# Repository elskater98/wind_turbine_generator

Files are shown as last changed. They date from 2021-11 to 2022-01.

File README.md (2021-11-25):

# Wind Turbine Generator

This repository takes part of the subject Ubiquitous Computing and Embedded systems project of the University of Lleida, being that one a development of a wind turbine generation farm, as for a real client.  

## Project statement

- Desing and evaluate a multi-purpose device including IoT capabilities.
- The main target is a Wind Turbine Generator Farm (WTGF).
- The engineering department has designed a prototype.
- Our target is to evaluate the prototype and determine its weaknesses.
- The prototype is composed by multiple devices; Supervision station, Data providers and a MQTT Broker.

## Project requirements

- There is just only one Supervision Station for the whole WTGF.
- All sensors are placed far from the Supervision Station.
- Temperature and humidity sensors are placed near to the Rotor Hub.
- The Tower movement sensor is placed in the middle of the tower.
- Sensor measurements must be obtained in Real-Time.
- Sensors are controlled by the Data providers and they will show the current sensor readings.
- Whole WTGF data is transferred to the Supervision Station through a MQTT broker.
- The MQTT broker will show graphically the current number of subscribers.
- The maintenance manager requires access to the last 24h data that should be available graphically on the Supervision Station.

## Prototype Schema


## Data Producer 1
### Material
- ESP-01 -> 3.3 V
- Protoboard 
- LCD Screen
- DHT11 -> 3.5 V
- VCC Protoboard adapter (3.3V, 5V)
- ESP Programmer module
- Wires

## Data Producer 2
### Material
- ESP-01 -> 3.3 V
- Protoboard 
- LCD Display
- Accelerometer (ADXL345) -> 3.3 V
- VCC Protoboard adapter (3.3V, 5V)
- ESP Programmer module
- Wires
- I2C – LCD Adapter

## MQTT Broker
### Material
- NodeMCU
- Breadboard
- MCP23017
- Wires
- Segment LED Bar
- I2C Bus

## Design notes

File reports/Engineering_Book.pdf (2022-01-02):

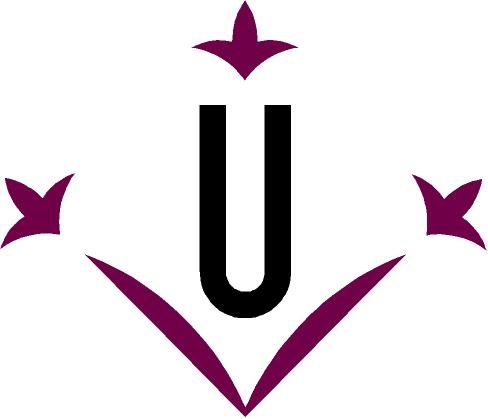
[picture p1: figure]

# University of Lleida

## Master’s Degree in Informatics Engineering

## Higher Polythecnic School

# Engineering Book

## Ubiquitous Computing and Embedded Systems

Francesc Contreras

Albert P´erez

Marc Visa

January 3, 2022

## Table of contents

1 Introduction | 1
2 Document structure | 1
3 Project statement | 2
3.1 Project requirements | | 3
3.2 User stories | | 3
4 Methodology | 4
5 Product Backlog Items | 5
6 Sprint Diary | 7
6.1 Sprint 1 | | 7
6.2 Sprint 2 | | 12
6.3 Sprint 3 | | 16
7 Project Flow | 20
8 Final Project Conclusions | 22

## List of Figures

1 | Electronic engineering department - WTGF Hardware Proposal | | 2
2 | Scrum methodology | | 4
3 | Sprint 1 - Cummulative-flow graph | | 10
4 | Sprint 1 - Burn-down graph | | 11
5 | Sprint 2 - Cummulative-flow graph | | 14
6 | Sprint 2 - Burn-down graph | | 15
7 | Sprint 3 - Cummulative-flow graph | | 18
8 | Sprint 3 - Burn-down graph | | 19
9 | Whole project flow | | 20
10 | Final project task table report | | 20
11 | Final project board view | | 21

## 1 Introduction

This document introduce the “Wind Turbine Generator Farm” (WTGF) project statement detailing the project requirements and the user stories related, since the aim is to concert the development process.

Hence, the purpose of this document is focused on describing the development of the project presenting the task distribution and the sprints made, but also, the suggestions related to the project that could improve it, and the situations/problems encountered with the proposed solutions.

In closing, there are the final project conclusions from the development team in charge of the project to remark their point of view.

## 2 Document structure

This section looks forward to narrating what is in each section of the document to help understand and facilitate the approach to the contents.

- Project statement: Introduction to the project, to set up the starting point for the whole project development.
- Methodology: Advance the methodology used during the development with some remarks because of the project.
- Product Backlog Items (PBI): The list including all the items present in the PBI, the final assigned score and their relation with the user stories.
- Sprint Diary: Detailed explanation for all the individual sprints during the project acting as a guideline of the process and the work done.
- Final project conclusions: Complete end of the line resulting from the development and over the realization of this document as well as from working with such embedded components and some contributions regarding personal opinion.

1

## 3 Project statement

The following is listed the starting point of the project:

- We work on developing embedded components able to manage and supervise machines.
- We have received a petition to design and evaluate a multi-purpose device including Internet of Things (IoT) capabilities.
- The main target is a Wind Turbine Generator Farm (WTGF).
- The engineering department has designed a prototype (Fig. 2).
- Our target is to evaluate the prototype and determine its weaknesses.
- The prototype is composed by multiple devices; the Supervision station (Data Consumer), the Data Producers and a MQTT Broker.

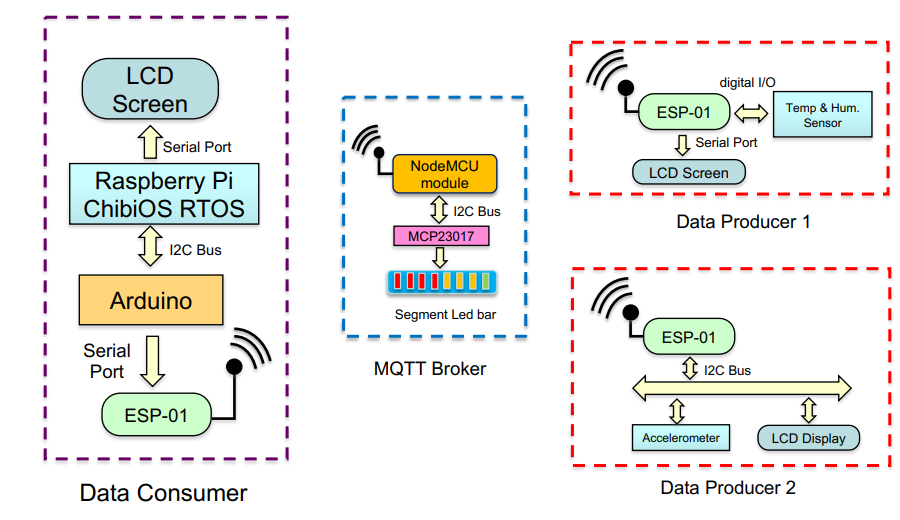
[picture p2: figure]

Figure 1: Electronic engineering department - WTGF Hardware Proposal

2

### 3.1 Project requirements

The following are the requirements presented:

- There is just only one Supervision station for the whole WTGF.
- All sensors are placed far from the Supervision station.
- Temperature and humidity sensors are placed near to the Rotor Hub.
- The Tower movement sensor is placed in the middle of the tower.
- Sensor measurements must be obtained in Real-Time.
- Sensors are controlled by the Data producers and they will show the current sensor readings.
- Whole WTGF data is transferred to the Supervision station through a MQTT Broker.
- The MQTT Broker will show graphically the current number of subscribers.
- The maintenance manager requires access to the last 24h that should be available graphically on the Supervision station.

### 3.2 User stories

The following are the features/goals to achieve:

- It is necessary to obtain the temperature and humidity at the top of the WTFG.
- It is necesssary to determine the WTFG tower movement.
- Sensor data must be must be sent to a Supervision station.
- MQTT Broker must show the current number of connections (percentatge).
- Maintenance manager requires graphically representation of the obtained sensor data, within the last 24h, in the Supervision station.

3

## 4 Methodology

At the project start-up, one of the main anchors that should be defined is the development methodology. In our case, as we were forming a group of engineers to work together, and because of the requirements, the Scrum methodology got the place.

Scrum is an agile development methodology, currently commonly widespread, based on an iterative and incremental processes. The primary objective of Scrum is to satisfy the customer’s need through an environment of transparency in communication, collective responsability and continuous progress.

In this way, we could define sprints and assure a quick an understandable communication to the customers/stakeholders, even doing two-week reports and progress presentations.

Although we must remark, as we were not full-time dedicated to this project, the daily-meetings were replaced by two-three days meetings. Thus, each team member reported the progress after a quite enough time.

Regarding the tasks that compose the product backlog item (PBI), they were defined and assigned by consensus of the whole development team. Moreover, the estimation story point for each item/task was calulated via the Scrum Poker technique through the next webpage https://scrumpoker.online/ where you can adapt anonymous sessions for each of the participants, thus, we assure a better task ponderation without influence obtaining approximate realistic story points.

Furthermore, we were using a Github repository to keep all the work done, but also, the Zenhub integated tool to manage the Scrum methodology.

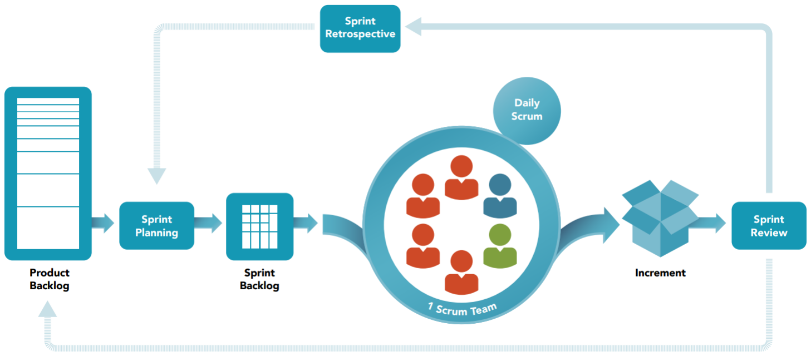
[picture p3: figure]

Figure 2: Scrum methodology

4

## 5 Product Backlog Items

The following is the final PBI of the project. For each task is specified the final assigned score, and the topic related to the user story.

You may see, at the beginning, lots of tasks related to ”Learning” stuff as we needed to introduce ourselves to those components and environments to work with. Since then, there are more concrete ones focused on the development of the project.

Item | Label | Story Point
Revise Material | Good first issue | 2
Read Documentation ESP-01 | Learning | 3
Read Documentation DHT11 | Learning | 3
Prepare Arduino Environment | Learning | 3
First contact with electronic components | Learning | 8
Read Documentation Accelerometer ADXL345 | Learning | 3
Read documentation MCP23017 | Learning | 3
Read documentation LCD Screen/Display | Learning | 2
Read documentation I2C Bus Protocol | Learning | 2
Prepare Raspberry Pi environment | Learning | 3
Read documentation about NodeMCU module | Learning | 3
Data Producer 1 development | Development | 8
Data Producer 2 development | Development | 8
Arduino interaction with ESP-01 | Development | 8
Install ChibiOS to Raspberry Pi | Development | 3
Data log and Screen representation | Development | 8

Table 1: Product Backlog 1/2

5

Item | Label | Story Point
Ultrasonic LED bar representation | Development | 8
Connect Raspberry Pi to LCD Screen via serial port | Development | 8
MQTT Broker development | Development | 13
Arduino interaction with Raspberry Pi | Bug | 8
Sprint 1 documentation | Documentation | 8
Sprint 2 documentation | Documentation | 8
Sprint 3 documentation | Documentation | 8
Data Producer 1 documentation | Documentation | 8
Data Producer 2 documentation | Documentation | 8
MQTT Broker documentation | Documentation | 5
Supervision Station documentation | Documentation | 8
Test Supervision Station | Testing | 13
Test MQTT Broker | Testing | 8
Test Data Producer 1 | Testing | 5
Test Data Producer 2 | Testing | 8

Table 2: Product Backlog 2/2

Finally, there are 31 tasks, getting a total of 194 story points at the end of the project.

6

## 6 Sprint Diary

The purpose of this section is to illustrate the several sprints carried out during the development of the project. In kind, for all individual sprints are detailed:

a) Sprint definition - A short self-explaining sentence related to the user story that identify the sprint goal.
b) Backlog tasks assigned to the sprint.
c) Dedication time to each task (an estimation in hours for the whole team).
d) Percentatge of Sprint completion (or individual tasks).
e) Sprint Review - A short conclusion on the present Sprint, and if required the new PBI organitzation. It could also include any comment related to the team (problems, suggestions, tasks assignments, etc).

### 6.1 Sprint 1

### 6.1.1 Sprint Definition

This first sprint aimed to introduce the team to work with the hardware components and their corresponding software, how to program. Once the team is introduced to the hardware and software of the components, the worked user stories for this sprint were the following:

1. As a user I would like to know to obtain the temperature and humidity at the top of the Wind Turbine Generator.
(a) Acceptable Criteria
i. The Data Producer 1 uses ESP-01 to receive the data from the DHT11 sensor. ii. The ESP-01 sends the data obtained to the LCD Screen to visualize it.
(b) Related Task
i. Data Producer 1 Development.
2. As a user I would like to know the Wind Turbine Generator tower movement.
(a) Acceptable Criteria
i. Data Producer 2 uses ESP-01 to receive the data from the ADXL345 sensor. ii. The ESP-01 sends the data obtained to the LCD Display to visualize it.
(b) Related Task
i. Data Producer 2 Development.

The first user story corresponded to the work-block named Data Producer 1, which components related to were:

- ESP-01
- Temperature and humidity sensor (DHT11)
- LCD Screen

7

The second user story corresponded to the work-block named Data Producer 2, which components related to were:

- ESP-01
- I2C Bus
- Accelerometer (ADXL345)
- LCD Display

Therefore, the sprint goal for this sprint 1 was to have a working version of the Data Producer 1 and the Data Producer 2 of the project, once the team got introduced to work with such components.

### 6.1.2 Sprint Backlog tasks

Task | Label | Story Point
Revise Material | Good first issue | 2
Read documentation ESP-01 | Learning | 3
Read documentation DHT11 | Learning | 3
Prepare Arduino environment | Learning | 3
First contact with electronic components | Learning | 8
Read documentation Accelerometer ADXL345 | Learning | 3
Data Producer 1 development | Enhancement | 8
Data Producer 2 development | Enhancement | 8
Sprint 1 documentation | Documentation | 8
Read documentation LCD Screen/Display | Learning | 3
Read documentation I2C Bus Protocol | Learning | 3
Test Data Producer 1 | Testing | 5
Test Data Producer 2 | Testing | 8

The total story points for the Sprint 1 are 55 points. We should remark this punctuation, as not having previous sprints, are not accurate to the amount of work the team could manage. Just an approximation.

8

### 6.1.3 Dedication time and completion percentage to each task

Task | Completion (%) | Team dedication time (h)
Revise Material | 100 | 1
Read documentation ESP-01 | 100 | 2
Read documentation DHT11 | 100 | 2
Prepare Arduino environment | 100 | 1
First contact with electronic components | 100 | 4
Read documentation Accelerometer ADXL345 | 100 | 2
Data Producer 1 development | 100 | 5
Data Producer 2 development | 20 | 2
Sprint 1 documentation | 100 | 3
Read documentation LCD Screen/Display | 100 | 2
Read documentation I2C Bus Protocol | 100 | 3
Test Data Producer 1 | 100 | 3

The total dedication time for this Sprint 1 is 30h, which means that for 14 days that the sprint lasted, the team dedicated 2:15h per day approximately.

9

### 6.1.4 Sprint Review

The team expected to get the two Data Producers as they are similar but it was realized that it was not as easy as expected when problems arise. The Data Producer 1 was done, just needed a quick clean of the code and integration with the broker, and for the Data Producer 2 needed more work on the I2C Bus.

Finally, the team finished this first sprint with 85% (47/55) of the tasks done, which meant that needed to adjust the number of story points for the next sprint.

The team worked well together and the sprint advanced smoothly. Although everything was new to all of us, from working with Scrum to the chosen technologies, we were well integrated, everyone was very supportive and open to researching, learning, and even teaching if necessary.

Lastly, it is needed to adjust the next sprint amount of story points, so as to finish the remaining tasks/issues for the Data Producer Development, but also taking into account the hours approximatly the team will be able to work on the next sprint.

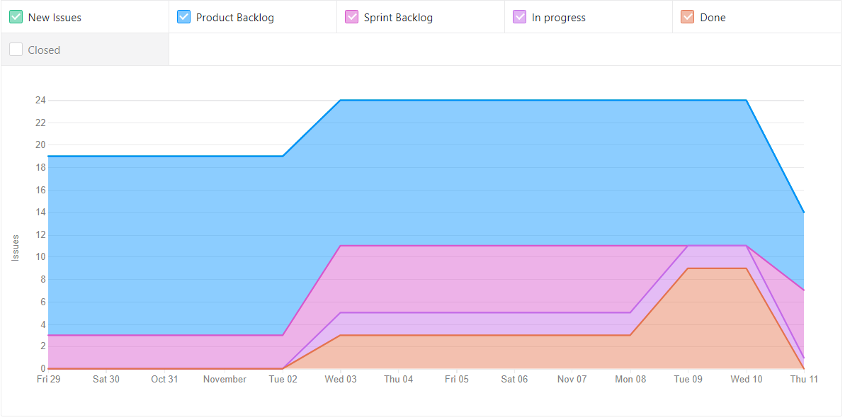
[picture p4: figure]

Figure 3: Sprint 1 - Cummulative-flow graph

10

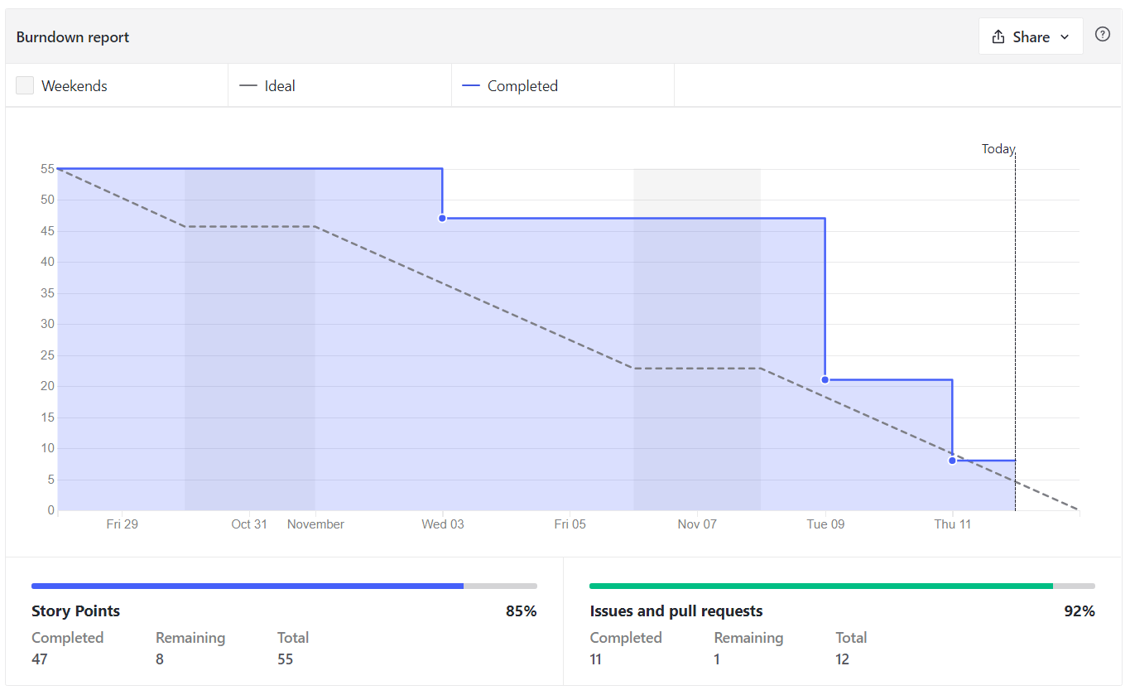
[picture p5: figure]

Figure 4: Sprint 1 - Burn-down graph

11

### 6.2 Sprint 2

### 6.2.1 Sprint Definition

The goal for this sprint was to finish the working version of the Data Producer 2 and having a working version of the MQTT Broker. The user stories that the team worked with during this sprint are the following:

### 6.2.2 User stories

1. As a user I would like to know the Wind Turbine Generator tower movement.
(a) Acceptable Criteria
i. Data Producer 2 uses ESP-01 to receive the data from the ADXL345 sensor. ii. The ESP-01 sends the data obtained to the LCD Display to visualize it.
(b) Related Task
i. Data Producer 2 Development.
2. As a broker I would like to show the current number of connections as a percentage.
(a) Acceptable Criteria
i. The MQTT Broker will receive data from Data Producer 1. ii. The MQTT Broker will receive data from Data Producer 2.
(b) Related Task
i. MQTT Broker Development.
3. As a broker I would like to send received sensor data to a Supervision Station.
(a) Acceptable Criteria
i. The MQTT Broker is able to subscribe to the correspondents topics provided by DP1 and DP2.
ii. The MQTT Broker is able to publish the data received.
(b) Related Task
i. MQTT Broker Development.

The first user story corresponded to the work-block named Data Producer 2, which components related to were:
- ESP-01
- I2C Bus
- Accelerometer (ADXL345)
- LCD Display

The second and third user story corresponded to the work-block named MQTT Broker, which components related to were:
- NodeMCU module
- MCP23017
- Segment LED Bar

12

### 6.2.3 Sprint Backlog tasks

Task | Label | Story Point
Read documentation MCP23017 | Learning | 3
Test MQTT Broker | Testing | 8
Test Data producer 2 | Testing | 8
Data producer 2 development | Enhancement | 13
MQTT Broker development | Enhancement | 13
Read Documentation about NodeMCU module | Learning | 3
Documentation Sprint 2 | Documentation | 8
Data producer 2 documentation | Documentation | 8
MQTT Broker documentation | Documentation | 5

The total story points for the Sprint 2 were 69 points.

### 6.2.4 Dedication time and completion percentage to each task

The total dedication time for the Sprint 2 was 35h, which means that for 14 days that the sprint lasted, the team dedicated 2:30h per day approx.

Task | Completion (%) | Team dedication time (h)
Read documentation MCP23017 | 100 | 2h
Test MQTT Broker | 100 | 1h
Test Data producer 2 | 100 | 2h
Data producer 2 development | 100 | 12h
MQTT Broker development | 100 | 8h
Read Documentation about NodeMCU module | 100 | 2h
Documentation Sprint 2 | 100 | 3h
Data producer 2 documentation | 100 | 2h
MQTT Broker documentation | 100 | 3h

13

### 6.2.5 Sprint Review

The goal for this sprint was to finish the Data Producer 2 module and the MQTT broker module. The team had a lot of difficulties throughout the sprint. Still, it was accomplished a working version of the Data Producer 2, retrieving and printing data from the accelerometer and a working version of the MQTT broker managing publications and subscriptions.

As a result, the team finished this second sprint with a 100% of tasks done, which meant that it is likely to finish the project on time, since in the last sprint it will be worked on the third and last module of the project.

The team worked well together and the sprint advanced smoothly. From now on the team prepared the last issues and tasks to work on the last sprint and hope that the project will be finished by the end of the third sprint if problems will not arise.

Therefore, for the last sprint the team focused on configuring the environment of the Raspberry Pi and installing the ChibiOS, but also on the Arduino, at first, working on the interaction with the corresponding ESP-01, and finally, with the Raspberry PI. Finally, it is also needed to adjust all the components in order to work together following the project schema, and testing all the time if they work properly.

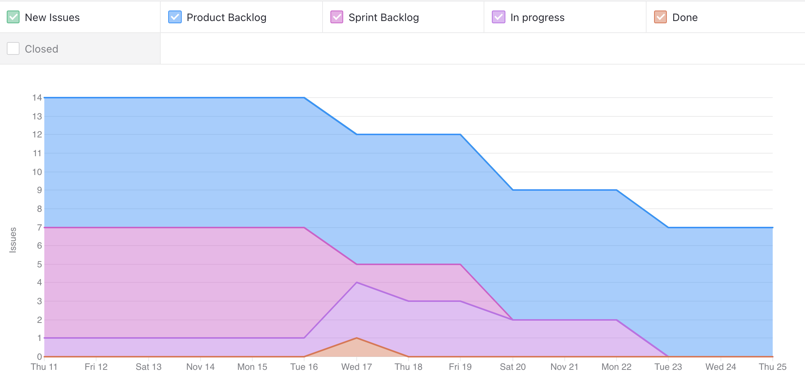
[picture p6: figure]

Figure 5: Sprint 2 - Cummulative-flow graph

14

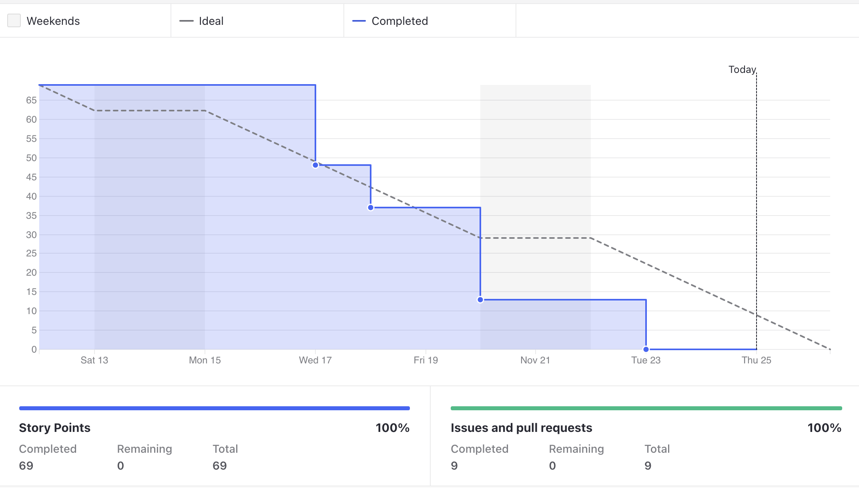
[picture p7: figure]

Figure 6: Sprint 2 - Burn-down graph

15

### 6.3 Sprint 3

### 6.3.1 Sprint Definition

The goal for this sprint was to have a working version of the Supervision Station, which corresponds to the Data Consumer module of the project. The user story that the team worked during this sprint is the following:

### 6.3.2 User stories

1. As a Maintenance manager I would like to represent graphically the obtained sensor data, within the last 24h, in the Supervision Station.
(a) Acceptable Criteria:
i. The Arduino UNO connects to the ESP-01 in order to get the data produced by the Data Producers
ii. The Raspberry Pi connects to the LCD Screen in order to represent the data from the Data Producers
iii. The Arduino UNO and the Raspberry Pi are linked by an I2C Bus where the Raspberry Pi will be the master and the Arduino UNO will be the slave.
iv. The ESP-01 receives the data obtained from the MQTT Broker, which has the data from Data Producer 1 and Data Producer 2.
v. We can see the data provided by the MQTT Broker.
(b) Related Task:
i. Supervision Station Development.

The user story corresponds to the work-block named Data Consumer, which components related to are the following:

- ESP-01
- Arduino UNO
- Raspberry Pi
- LCD Screen

16

### 6.3.3 Sprint Backlog tasks

For this sprint, the total story points is 86 points. This may seem too much compared to the previous sprints, but they wanted to get focused on all task related to the Supervision Station as the last step to conclude the project.

In this way, for the last sprint we expected to finish the remaining tasks if any, and work on the integration of all project parts.

Task | Label | Story Point
Prepare Raspberry Pi environment | Learning | 3
Install ChibiOS to Raspberry Pi | Enhancement | 2
Arduino interaction with R.Pi | Enhancement | 13
Connect Raspberry Pi to LCD Screen via serial port | Enhancement | 8
Arduino interaction with ESP-01 | Enhancement | 8
Test Supervision Station | Testing | 13
Data Consumer: Data log and Screen representation | Enhancement | 13
Sprint 3 documentation | Documentation | 13
Supervision Station documentation | Documentation | 13

### 6.3.4 Dedication time and completion percentage to each task

Task | Completion (%) | Team dedication time (h)
Prepare Raspberry Pi Environment | 100 | 1h
Install ChibiOS to Raspberry Pi | 100 | 1h
Arduino interaction with R.Pi | 80 | 3h
Connect Raspberry Pi to LCD Screen via serial port | 100 | 2h
Arduino interaction with ESP-01 | 50 | 2h
Test Supervision Station | 80 | 5h
Data Consumer: Data log and Screen representation | 70 | 4h
Sprint 3 documentation | 100 | 3h
Supervision Station documentation | 25 | 1h

17

The total dedication time for the Sprint 3 was 22 hours.

The dedication time to this sprint was not as much compared to the others as it can be observed. About 1.5 hours per day. Basically, due to some issues encountered which slowed-down the development, and a short vacation period in mid-sprint.

On the other hand, the main purpose of the sprint was accomplished, as the team got a working version of the Data Consumer, but waiting to test it all.

### 6.3.5 Sprint Review

The main reasons why the team slowed down the development were that they got issues with some failing wires when treating with the SDA connection between the Raspberry Pi and the Arduino when building the component schema for the I2C bus. And also, with the LCD Screen, the one needed for multiple testing because they couldn’t work properly on it since it was failing. Thus, implying not being able to work fairly on the graphics representation, nor even see the values received from the Arduino.

Hence, it can be observed the “Arduino interaction with R.Pi” task and the ”Test Supervision Station” task are not completely finished, specifying a symbolic 80 percent.

In this way, the team should work on finishing and testing the graphics representation on the LCD Screen. Moreover, remained to conclude the Arduino interaction with the ESP to get dynamically the data (this corresponds to the project parts integration), because it could not be dedicated so much time due to the mentioned problems above.

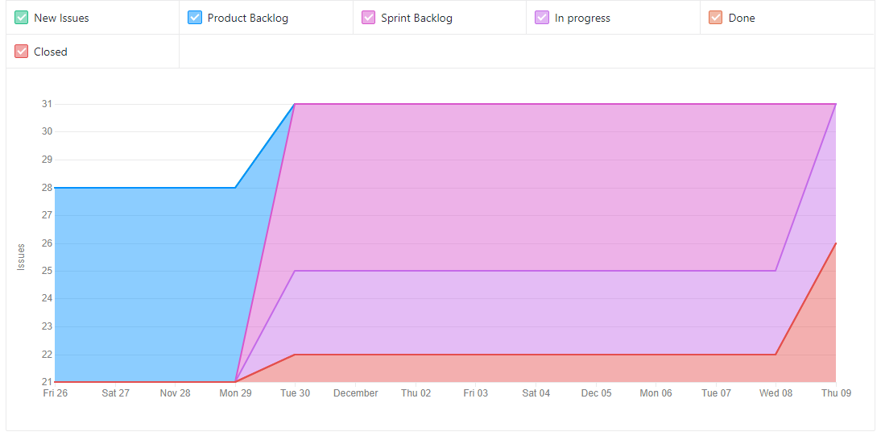
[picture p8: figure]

Figure 7: Sprint 3 - Cummulative-flow graph

18

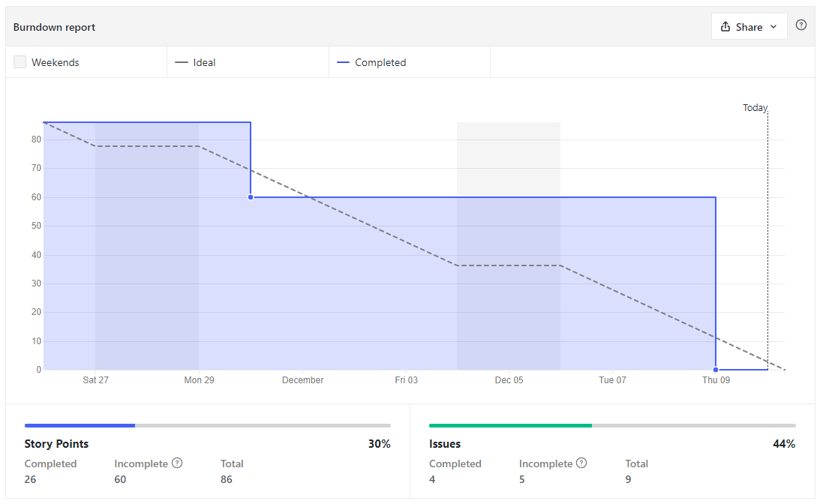
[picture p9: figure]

Figure 8: Sprint 3 - Burn-down graph

From now on the team shall prepare the last issues and tasks to work on the last sprint and they thought that if they keep working as they have done, the project will be finished in time.

Although, the team must got focused on solving the issues encountered on this sprint to finish the remaining tasks and test them all. Mainly the Raspberry Pi and Arduino interaction. And finally, test the whole project parts integration, and carried out the final project documentation.

19

## 7 Project Flow

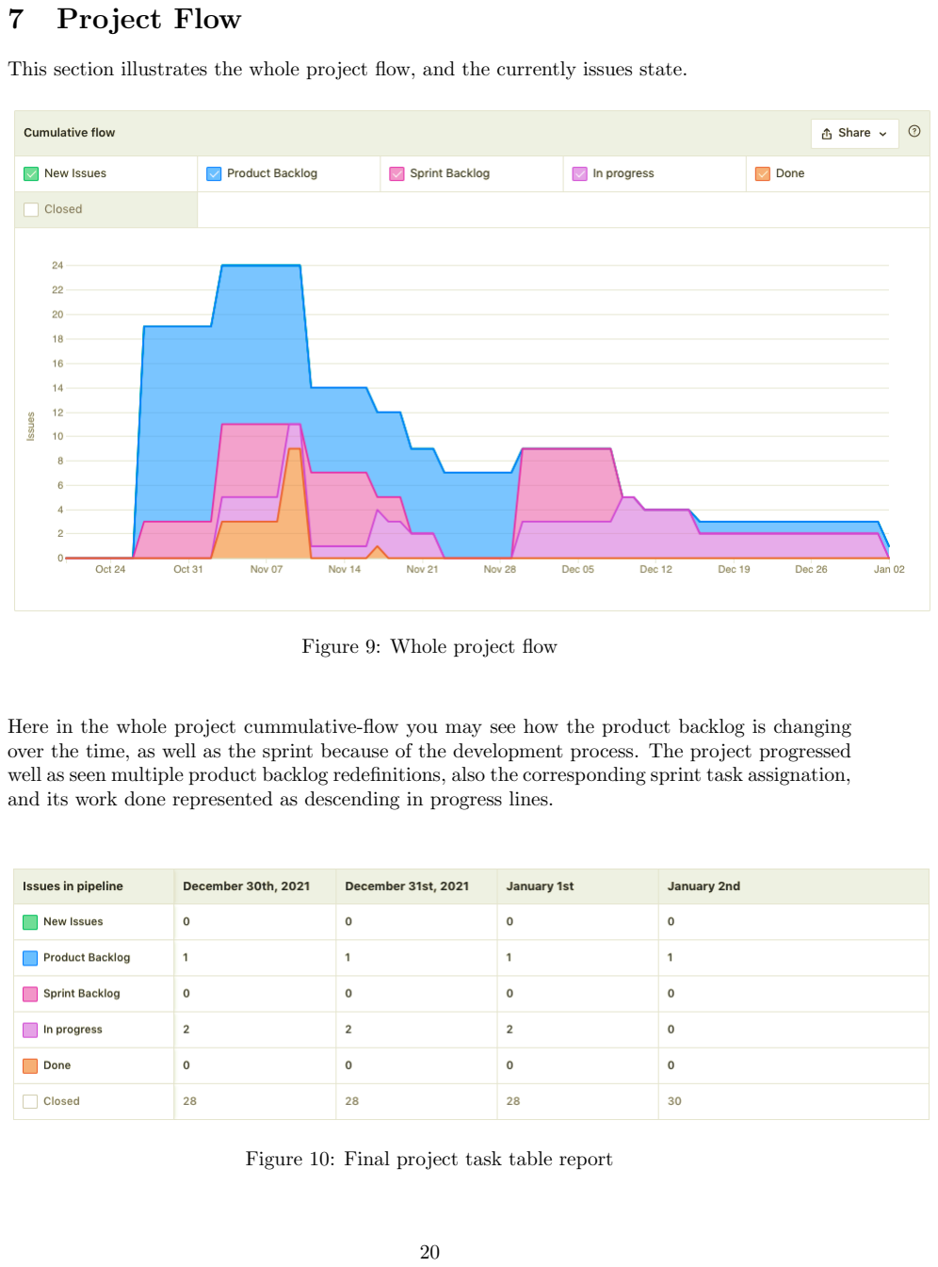
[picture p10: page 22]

This section illustrates the whole project flow, and the currently issues state.

Figure 9: Whole project flow

Here in the whole project cummulative-flow you may see how the product backlog is changing over the time, as well as the sprint because of the development process. The project progressed well as seen multiple product backlog redefinitions, also the corresponding sprint task assignation, and its work done represented as descending in progress lines.

Figure 10: Final project task table report

20

Even though, there is one last issue in the product backlog which corresponds to “Arduino interaction with R.PI”. The one meant a problem for us, due to the impossibility to carry out the communication thourgh an I2C Bus amonb these components. There is more specific criteria in the technical documentation you may find in the github repository.

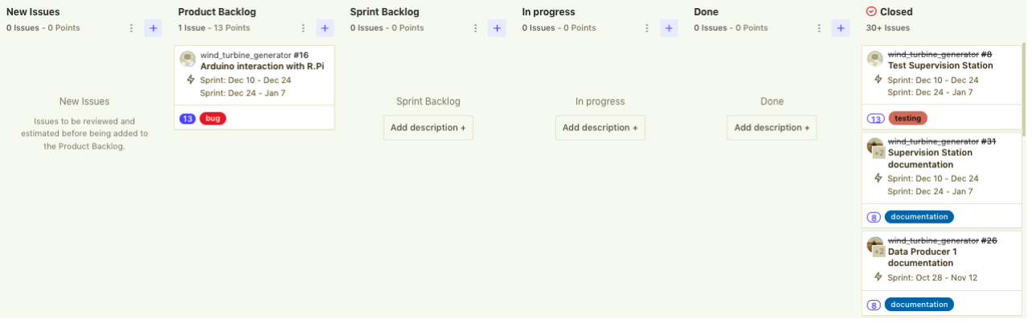
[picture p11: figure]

Figure 11: Final project board view

Overall, the project got its final face even encountering a few problems, thus, having one issue in the product backlog. But, as the main objective was to evaluate the optimum solution to the presented user stories, this last issue doesn’t meant that much as there is a better solution proposal done. See technical documentation.

21

## 8 Final Project Conclusions

As the development team of this project, we would like to write down some suggestions, conclusions, improvements regarding the development process, regarding the proposed solutions and our personal opinion as regards the subject’s project.

We think that this kind of project is ideal to get started with micro-controllers and learn about embedded systems, the concept of IoT and the ubiquitous computing. Furthermore, it is perfect to hone our technical skills regarding electronics and programming. Along with the IoT concept, this project allows you to further your network management. Besides, the fact that you can obtain and transfer data from remote sensors very interesting.

Despite these advantages, the inconveniences that we have learnt from this kind of project is that you need to work patiently and very careful and meticulous, because although your code would execute fine, the components might be worn away or broken and the module you are working will fail.

As regards the components used for this project, we propose that, in future projects of the subject, they shall be replaced by state-of-the-art ones, so as to diminish the possible problems that future students might encounter.

To conclude, we would just like to point out that we really liked the way the project was approached. That is, we were presented with a statement to analyze and propose a functional solution, but with total freedom to decide whether the initially proposed scheme was optimal or not, also being able to adapt the solution to the problems that can be found. In our case, due to certain problems and schema analysis considerations of the initial solution, we were able to propose the best way to carry out the project.

22

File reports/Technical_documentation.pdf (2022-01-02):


# University of Lleida

## Master’s Degree in Informatics Engineering

## Higher Polythecnic School

# Technical Documentation

## Ubiquitous Computing and Embedded Systems

Francesc Contreras

Albert P´erez

Marc Visa

January 3, 2022

## Table of contents

1 Introduction | 1
2 Data Producer 1 | 2
3 Data Producer 2 | 4
4 MQTT Broker | 6
5 Data transmission | 10
6 Supervision Station | 13
7 Project Source Code | 19
Appendices | 20
A Data Producer 1 | 20
B Data Producer 2 | 20
C MQTT Broker | 21
D MQTT Explorer | 22

## List of Figures

1 | Wind turbine generator prototype schema | | 1
2 | Data Producer 1 Wiring Schema | | 3
3 | Data Producer 2 Wiring Schema | | 5
4 | MQTT Broker Diagram | | 7
5 | MCP23017 Schema | | 7
6 | MQTT Explorer for Data Producer 1 | | 10
7 | MQTT Explorer for Data Producer 1 History and values | | 11
8 | MQTT Explorer History chart | | 11
9 | MQTT Explorer for Data Producer 2 | | 12
10 | MQTT Explorer for both Data Producers | | 12
11 | Solution A Schema | | 16
12 | Solution B Schema | | 18
13 | Data Producer 1 Assembly | | 20
14 | Data Producer 2 Assembly | | 20
15 | Data Producer 2 in movement | | 21
16 | MQTT Broker Assembly | | 21
17 | Temperature Changes | | 22
18 | Acceleration Changes | | 22
19 | Humidity History | | 23
20 | Comparison between Solution B and C | | 23

## 1 Introduction

The purpose of this document is to show the technical documentation of the “Wind Turbine Generator Farm” (WTGF) project which is about designing, testing, and working with microcontrollers simulating.

It will consist of, for each module of the project, its wiring schema, its environment preparation and its development explanation. Furthermore, it will contain the data transmision protocol explained for our project case and some relevant content just to improve the module development explanation.

The motivation lies on providing a full guideline to whoever is interested in the project, and its solution proposal.


Figure 1: Wind turbine generator prototype schema

1

## 2 Data Producer 1

The objective of this module is to get the temperature and the humitity at the top of the wind turbines. Moreover, displaying those values into a LCD Screen in case of in-situ visualization, but also, provide them through a WI-FI interface enabling the collection of this data.

### 2.1 Environment

At first, these are the steps for installing the libraries and setting up the Arduino IDE to get started for the Data Producer 1 development:

1. Install Arduino IDE v.1.8.16. (https://www.arduino.cc/en/software)
2. Install driver (http://www.wch.cn/download/CH341SER_EXE.html) for USB adapter to ESP-01 and switch the interrupter to PROG mode.
3. Install ESP8266 Board from Boards Manager from Arduino IDE.
4. Install the following libraries from the Manage Libraries of Arduino IDE:
(a) DHT 1
library by Adafruit.
(b) Adafruit Unified Sensor by Adafruit.
5. Install the following libraries from GitHub: (These libraries should be added to the Arduino/libraries folder):
(a) PubSubClient² (https://github.com/knolleary/pubsubclient)
6. Connect the ESP-01³ along with the USB adapter to your machine.
7. Code the program for the ESP-01 and DHT11.

### 2.2 Material

Subsequently, you will find all the required components for the Data Producer 1, and a short explanatory description for those not so common.

- ESP-01 (3.3 V): it is a Wi-Fi module that allows microcontrollers access to a Wi-Fi network.
- Breadboard: A board, having a matrix of small holes to which components may be attached without solder.
- LCD Screen (5V): it is a flat-panel display or other electronically modulated optical device that uses the light-modulating properties of liquid crystals combined with polarizers.
- DHT11 (3.3V): it is a basic, ultra low-cost digital temperature and humidity sensor.
- VCC Protoboard adapter (3.3V, 5V)
- ESP Programmer module
- Wires

1Temperature and humidity sensor
2MQTT Library
3Low-cost WiFi microchip with built-in TCP/IP networking software, and micro-controller capability

2

### 2.3 Wiring Schematics

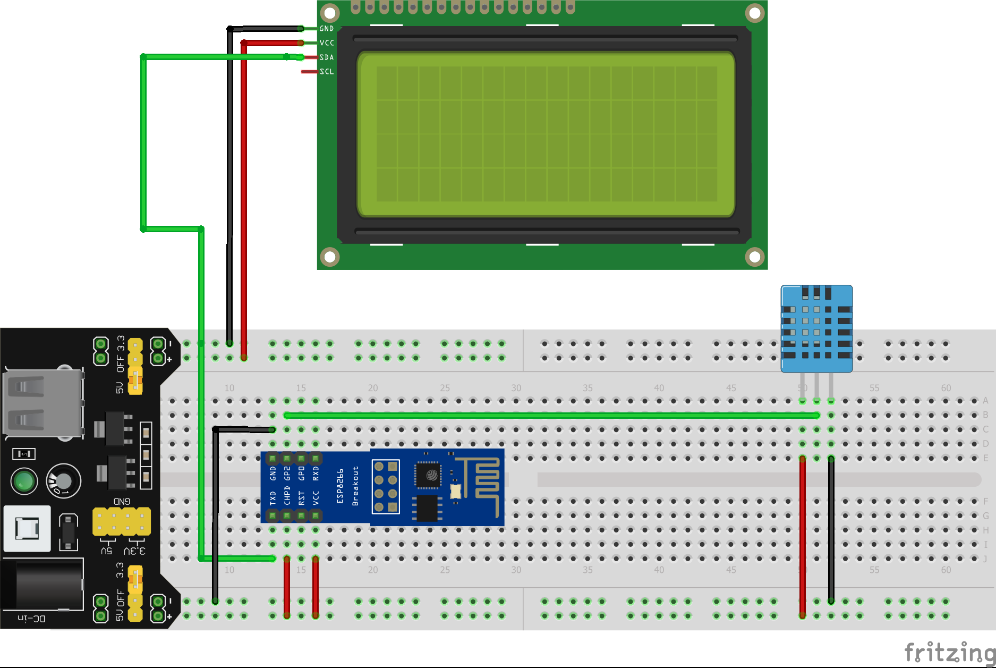
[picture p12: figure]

Figure 2: Data Producer 1 Wiring Schema

Pay Attention!
In our LCD Screen we don’t have SDA and SCL connections, we have RX and TX, then our RX is SDA and TX is SCL in Figure 11.

3

## 3 Data Producer 2

The objective of this module is to register the movement of the wind turbines. In this way, it will get the space components (x, y, z) from the accelerometer sensor, thus, enabling to find out the total acceleration by time unit of the tower. Also, it will display the values into a LCD Display, and provide them via a WI-FI interface.

### 3.1 Environment

At first, these are the steps for installing the libraries and setting up the Arduino IDE to get started for the Data Producer 2 development:

1. Install Arduino IDE. (https://www.arduino.cc/en/software)
2. Install driver (http://www.wch.cn/download/CH341SER_EXE.html) for USB adapter to ESP-01 in PROG mode.
3. Install ESP8266 Board from Boards Manager from Arduino IDE.
4. Install the following libraries from the Manage Libraries of Arduino IDE:
(a) SparkFun ADXL345
(b) Adafruit Unified Sensor by Adafruit.
5. Install the following libraries from GitHub: (These libraries should be added to the Arduino/libraries folder):
(a) LiquidCrystal I2C⁴ (https://github.com/johnrickman/LiquidCrystal_I2C)
(b) PubSubClient⁵ (https://github.com/knolleary/pubsubclient)
6. Connect the ESP-01⁶ along with the USB adapter to your machine.
7. Code the program for the ESP-01.

### 3.2 Material

Subsequently, you will find all the required components for the Data Producer 2, and a short description for those not so common.

- ESP-01 (3.3 V): is a Wi-Fi module that allows micro-controllers access to a Wi-Fi network.
- Breadboard: A board, having a matrix of small holes to which components may be attached without solder.
- LCD Display (5V): is a flat-panel display or other electronically modulated optical device that uses the light-modulating properties of liquid crystals combined with polarizers.
- ADXL345 (3.3V): is an component that measures the acceleratometer, it allows us to use I2C or SPI .

4We use this custom library, because it correct the bugs related to ESP-01 using Arduino IDE v 1.8.16 5MQTT Library
6Low-cost WiFi microchip with built-in TCP/IP networking software, and micro-controller capability

4

- VCC Protoboard adapter (3.3V, 5V)
- ESP Programmer module
- I2C Bus: is an component that extends I2C Bus and allows us to use with another components such as LCD Display.
- Wires

### 3.3 Wiring Schematics

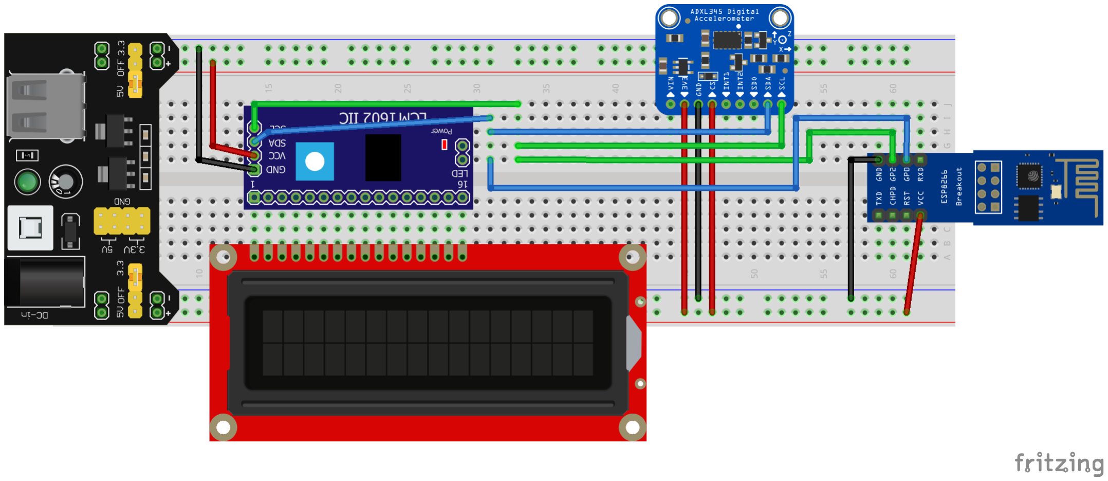
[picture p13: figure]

Figure 3: Data Producer 2 Wiring Schema

5

## 4 MQTT Broker

MQTT broker provides fast, efficient, and reliable movement of data to and from connected IoT devices. It uses MQTT protocol (http://docs.oasis-open.org/mqtt/mqtt/v3.1.1/mqtt-v3.1.1.html) to transmit and recive the data from the devices connected. Then, it will receive and make availble the data from the Data producers at the wind turbines to whom is subscribe to the corresponding topics.

### 4.1 Environment

Firstly, these are the steps for installing the libraries and setting up the Arduino IDE to get started for the MQTT Broker development:

1. Install ESP8266 Board from Boards Manager from Arduino IDE.
2. Install the following libraries from the Manager Libraries of Arduino IDE:
(a) Adafruit MCP23017
(b) Adafruit Unified Sensor by Adafruit.
3. Install the following libraries from GitHub: (These libraries should be added to the Arduino/libraries folder):
(a) uMQTTBroker (https://github.com/martin-ger/uMQTTBroker)
4. Select NodeMCU v1.0 as compilation environment.
5. Connect the NodeMCU v1.0 along with the micro-USB adapter to your machine.
6. Code the program for NodeMCU v1.0.

### 4.2 Material

Subsequently, you will find all the required components for the Data Producer 2, and a short description for those uncommon ones.

- NodeMCU: open source firmware for which open source prototyping board designs are available. The firmware is based on the eLua project, and built on the Espressif Non-OS SDK for ESP8266. Initially included firmware which runs on the ESP8266 Wi-Fi SoC from Espressif Systems, and hardware which was based on the ESP-12 module.[6][7] Later, support for the ESP32 32-bit MCU was added.
- Breadboard: A board, having a matrix of small holes to which components may be attached without solder.
- MCP23017: Component that measures the accelerometer sensor, it allows us to use I2C or SPI. It is a port expander that gives you virtually identical PORTS compared to standard micro-controllers e.g. Arduino or PIC devices and it even includes interrupts. It gives you an extra 16 I/O pins using an I2C interface as well as comprehensive interrupt control.
- Wires
- LED

6

### 4.3 Wiring Schematics

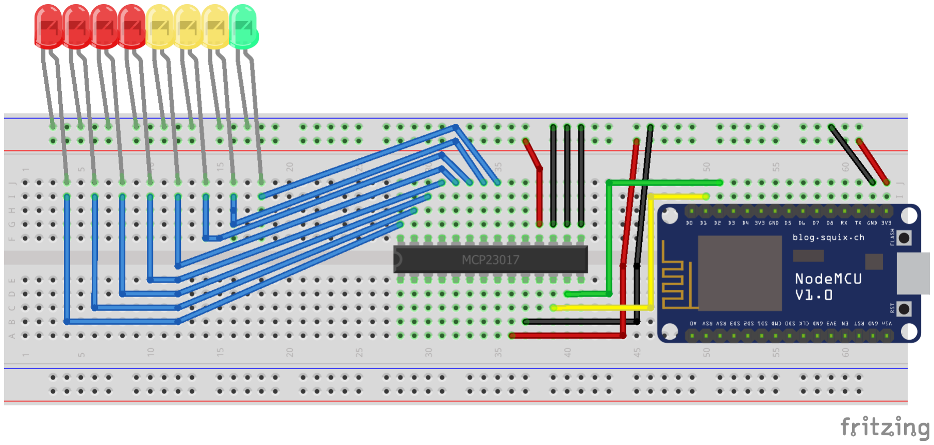
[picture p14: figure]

Figure 4: MQTT Broker Diagram

### 4.4 Connections Visualization

To control the connections to the MQTT Broker we decide to use LEDs that represents the number of subscribers that are connected. Then, we make use of the MCP component to enable far multiple pins for the simulated LED bar.

The functioning of the LED bar is, basically, one led activated for active connection.

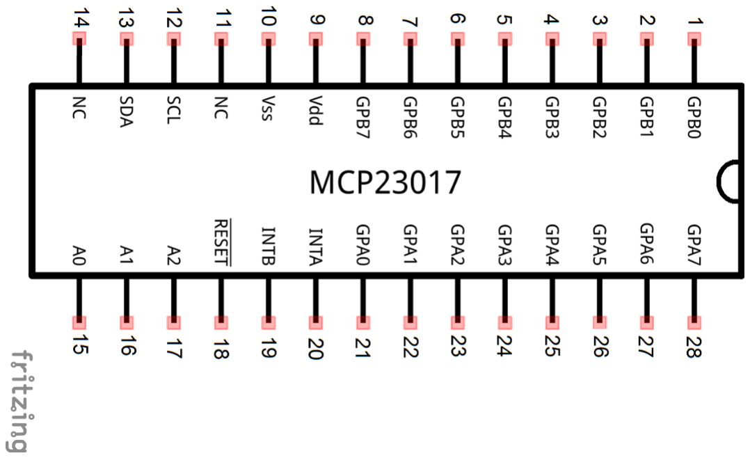
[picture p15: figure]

Figure 5: MCP23017 Schema

7

Adafruit PIN | Pin Name | Physical Pin
0 | GPA0 | 21
1 | GPA1 | 22
2 | GPA2 | 23
3 | GPA3 | 24
4 | GPA4 | 25
5 | GPA5 | 26
6 | GPA6 | 27
7 | GPA7 | 28
8 | GPB0 | 1
9 | GPB1 | 2
10 | GPB2 | 3
11 | GPB3 | 4
12 | GPB4 | 5
13 | GPB5 | 6
14 | GPB6 | 7
15 | GPB7 | 8

Table 1: Adafruit MCP23017 pin mapping

8

MCU Pin | MCU Pin Name | MCP23017 Pin | MCP23017 Pin Name
17 | D1 | 12 | SCL
18 | D2 | 13 | SDA
21 | 3V3 | 18 | Reset
21 | 3V3 | 9 | VDD
22 | GND | 10 | VSS
22 | GND | 15 | A0
22 | GND | 16 | A1
22 | GND | 17 | A2

Table 2: Our schema

For the testing process of the development, the team used the MQTT Explorer in order to check if there were real connections with the broker and also check if the Data Producers sent the data correctly.

Additionally, when testing, if a client was connected, that was coded as the green LED lighted, if only one client was connected. If two clients were connected, the green one and the first yellow one were lighted and so in succession.

9

## 5 Data transmission

This section reports how the data transmission works between the MQTT Broker and the other devices subscribed.

The transmission of the data uses MQTT Protocol (https://docs.oasis-open.org/mqtt/mqtt/v5.0/mqtt-v5.0.html) to transfer data between devices and the MQTT Broker. In our case, the MQTT Broker and the devices are connected to the same network to transmit and receive data. However, in the real world, most cases use a VPN⁷ to
connect the devices to MQTT Broker and access remotely from anywhere which is an awesome solution.

The following are detailed for each data producer device how its data is received and represented to whoever is interested in registering their values.

Note, that we are using the MQTT Explorer software to access the values of the broker.

### 5.1 Data Producer 1

In the first picture below, it can be seen the number of connections that the MQTT Broker has, along with the retrieved data from the temperature and humidity sensor.

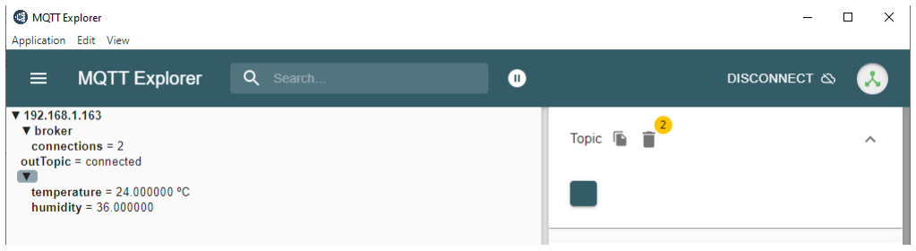
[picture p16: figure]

Figure 6: MQTT Explorer for Data Producer 1

For the second picture, it can be seen in the right side of the Explorer some information regarding the topics, values of the MQTT Broker. In this case, we have two topics, the humidity topic and the temperature topic. As for the values it can be observed a history of the temperature and humidity sensor values, which the broker has retrieved.

7Virtual Pricate Network

10

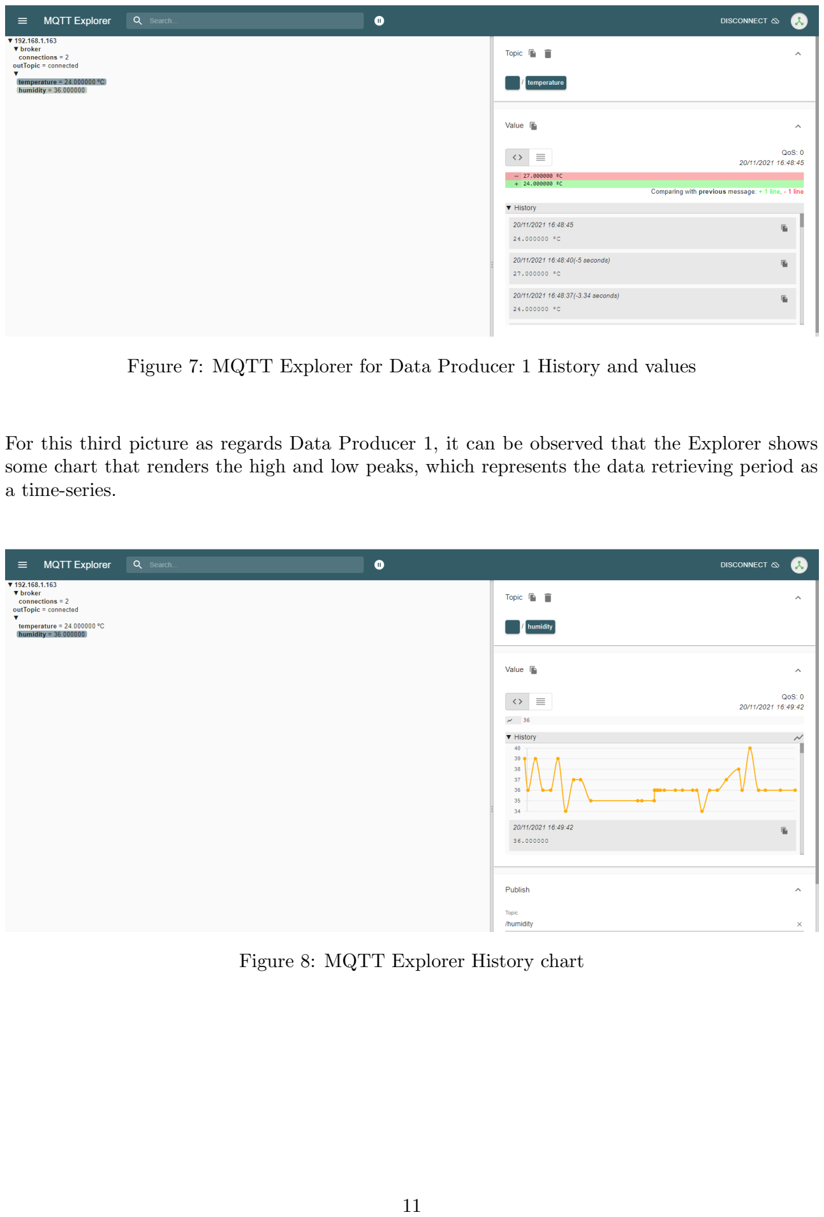
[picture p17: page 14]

Figure 7: MQTT Explorer for Data Producer 1 History and values

For this third picture as regards Data Producer 1, it can be observed that the Explorer shows some chart that renders the high and low peaks, which represents the data retrieving period as a time-series.

Figure 8: MQTT Explorer History chart

11

### 5.2 Data Producer 2

For the Data Producer 2 in the MQTT Broker, it is defined the acceleration topic, in which the accelerometer publishes the data and the Broker retrieves it.

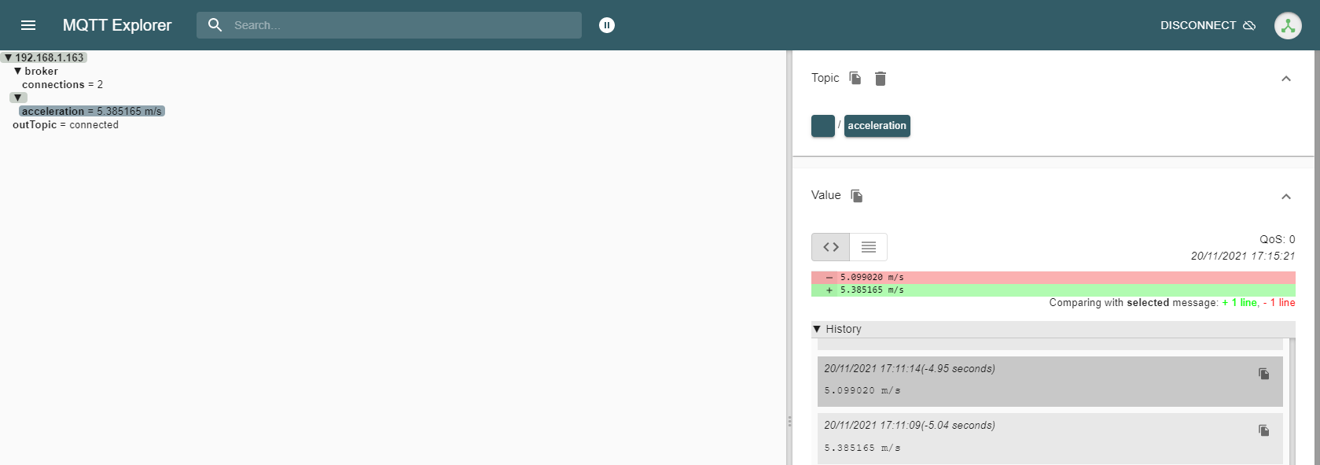
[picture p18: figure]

Figure 9: MQTT Explorer for Data Producer 2

### 5.3 Both Data Producers

For the last picture, it can be observed both Data Producers that are publishing data in the three mentioned topics previously (humidity, temperature, acceleration) and the MQTT is retrieving all the data by the topics and shows the values of the respective topics on the left part of the screen of the MQTT Explorer.

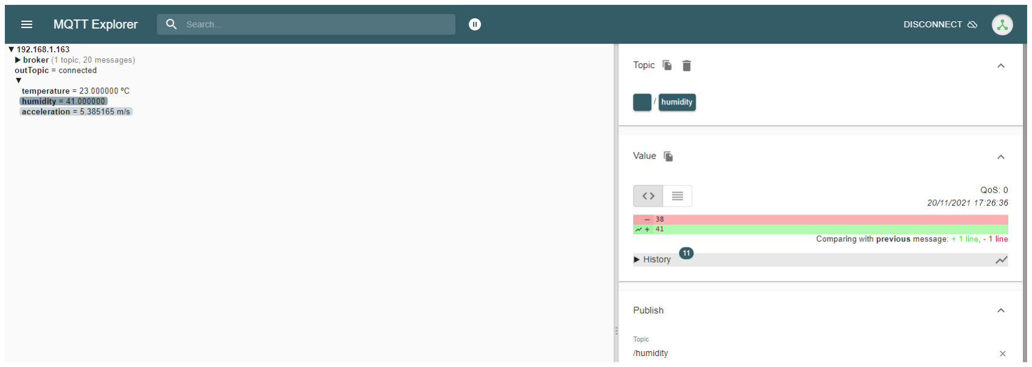
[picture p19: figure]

Figure 10: MQTT Explorer for both Data Producers

12

## 6 Supervision Station

The objective of this module is to collect the data from the MQTT Broker subscribing to its service, and make them accessible fo historical registering purposes.

This section will detail all to care about the Supervision station. At first, the environment and materials needed to accomplished the development are introduced. But the key section remarks on explaining the criteria and decisions taken while developing.

So, in the development section, the idea is to focused not only on detailing the final solution but also to care about all the steps and decisions taken during the process. In this manner, it makes sense the final solution when specifying its underground.

### 6.1 Environment

In this section, we will introduce you to preparing the environment to work and program the supervision station, and also for each of the main components involved is specified specific criteria to develop their functionalities.

Firstly, to work with the Arduino UNO and ESP-01 components we should,

1. Install Arduino IDE. (https://www.arduino.cc/en/software)

It is used in order to program the sketches, from which the components are based on to develop the supervision station functionality.

Subsequently, there are specific remarks for each of these components regarding the Arduino IDE dependencies such as libraries used, and some criteria about working with them.

As for the ESP-01:

1. Arduino IDE dependencies.
- Install driver (http://www.wch.cn/download/CH341SER_EXE.html) for USB adapter to ESP-01⁸
in PROG mode.
- Install ESP8266 Board from the Arduino IDE Boards Manager.
- Install the following libraries from GitHub: (These libraries should be added to the Arduino/libraries folder):
(a) PubSubClient⁹ (https://github.com/knolleary/pubsubclient)
2. Use a USB adapter to connect the ESP-01 to your machine in order to set up the sketch programmed.
3. Code the program/sketch.

8Low-cost WiFi microchip with built-in TCP/IP networking software, and micro-controller capability 9MQTT Library

13

As for the Arduino UNO:

1. Connect the Arduino Uno to your machine via USB to set up the sketch.
2. Code the program/sketch.

Then, the raspberry Pi is quite different as actually we were using a Linux distribution (Ubuntu), not an IDE, to develop its functionality. In this way, you will need a machine running Ubuntu if following our own way to work. The following are specified the dependencies and criteria to be taken into account.

As for the Raspberry Pi:

1. Install Developer ARM Toolchain
(a) Ubuntu:

sudo apt-get install gcc-arm-none-eabi

(b) Windows 10: gcc-arm-none-eabi (https://developer.arm.com/tools-and-software/open-source-software/developer-tools/gnu-toolchain/gnu-rm/downloads)
2. Download ChibiOS-RPi (https://github.com/steve-bate/Chibios-Rpi) for Raspberry Pi
3. Prepare SD-Card
(a) bootcode.bin (https://github.com/elskater98/wind_turbine_generator/blob/master/code/supervise_satation/chibiOS/bootcode.bin)
(b) start.elf (https://github.com/elskater98/wind_turbine_generator/blob/master/code/supervise_satation/chibiOS/start.elf)
4. Check arm-none-eabi-gcc

arm-none-eabi-gcc --version

5. Compile your code using ”make” command.
6. Rename the file build/ch.bin to kernel.img
7. Load kernel.img to SD-Card

14

### 6.2 Material

Next, you will find all the required components for the Supervision Station, and a brief description for those uncommon ones.

- Raspberry Pi: a low cost, credit-card sized computer that plugs into a computer monitor or TV, and uses a standard keyboard and mouse. It is a capable little device that enables people of all ages to explore computing, and to learn how to program in languages like Scratch and Python. It’s capable of doing everything you’d expect a desktop computer to do, from browsing the internet and playing high-definition video, to making spreadsheets, word-processing, and playing games.
- ChibiOS/RT: a compact and fast real-time operating system supporting multiple architectures and released under a mix of the GNU General Public License version 3 (GPL3) and the Apache License 2.0 (depending on module).
- Arduino UNO: a micro-controller board based on the ATmega328P (data-sheet). It has 14 digital input/output pins (of which 6 can be used as PWM outputs), 6 analog inputs, a 16 MHz ceramic resonator (CSTCE16M0V53-R0), a USB connection, a power jack, an ICSP header and a reset button. It contains everything needed to support the micro-controller; simply connect it to a computer with a USB cable or power it with a AC-to-DC adapter or battery to get started.. You can tinker with your Uno without worrying too much about doing something wrong, worst case scenario you can replace the chip for a few dollars and start over again.
- ESP-01: is a Wi-Fi module that allows micro-controllers access to a Wi-Fi network.
- LCD Serial Screen: is a flat-panel display or other electronically modulated optical device that uses the light-modulating properties of liquid crystals combined with polarizers.
- Breadboard: a board having a matrix of small holes to which components may be attached without solder.
- ESP Programmer module
- Wires

15

### 6.3 Development

The requirements were to use a Raspberry Pi to show historical data through an LCD Screen, from the data received from the Arduino via an I2C Bus communication. Moreover, the Arduino should get the data from the MQTT Broker from the topics set up, such as temperature, acceleration, and humidity.

In this way, the main idea was to apply a master-slave schema among the Raspberry PI and the Arduino respectively, and use an ESP-01 as a WIFI interface to enable the Arduino to subscribe to the MQTT Broker topics. The following is the wiring schema for our first proposal:

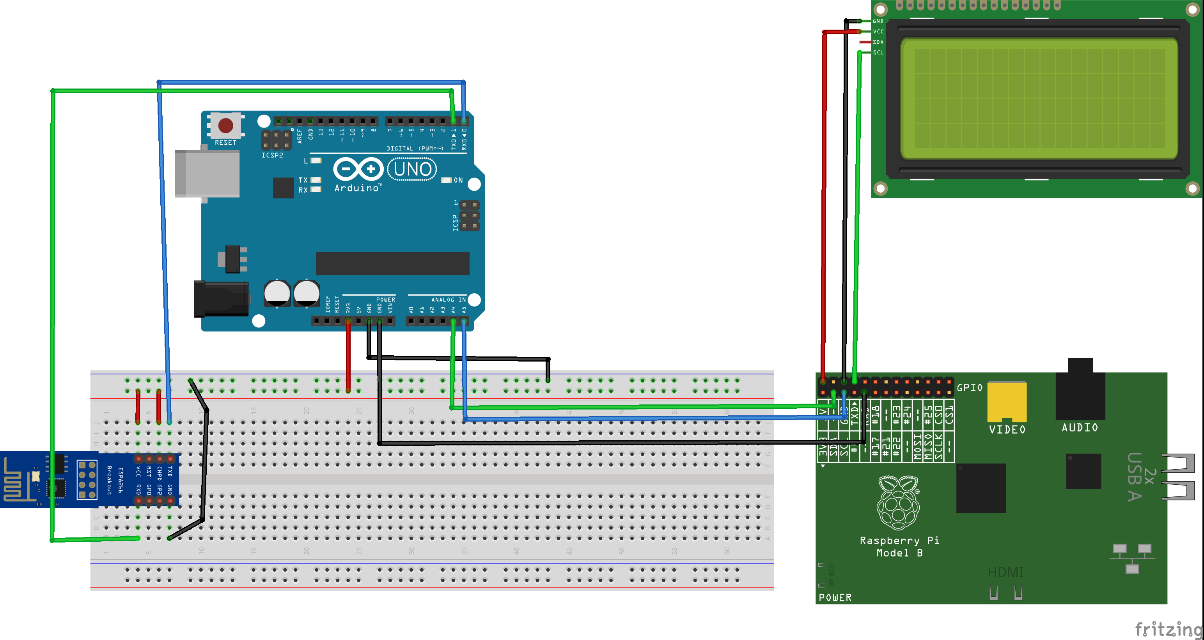
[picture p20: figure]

Figure 11: Solution A Schema

The good point of this solution is, basically, that the ESP-01 doesn’t have to be programmed, just configured through the Arduino sketch to work for it. Also, the master-slave schema will enable the Raspberry Pi to access the data Arduino is saving at the time required. But, it should be considered the capacity of the Arduino in the case of a scaling system. Apart from that possible constraint, we still think that the Raspberry Pi should be the master module in the communication.

To configure the ESP-01 as a WI-FI interface from the Arduino sketch you should use the AT Commands. But, in our case, the ESP-01 was not answering the orders. We found out that the original firmware was flashed as we previously uploaded some of our own sketches. So, we tried to reset the firmware to make the ESP-01 answer the AT Commands. Sadly, we couldn’t accomplished this approach.

We used multiple tools to upload some firmware but there was no way the ESP-01 answered the commands. We still think this is the best option and we encourage other teams to take it into account, but we needed to focus on not blocking the development and getting another solution.

16

Then, a second idea came up to encourage the project. Simply program the ESP-01 and use a client-server schema to pass the data to the Arduino throughout a custom protocol, not too complex, just to approximate the best efficient communication. As for the assembly scheme, it is the same as shown in the previous image.

The Arduino would request to the ESP-01, and this would send the subscribed data from the MQTT Broker. In our case, the temperature, humidity, and acceleration.

The data will be sent as a particular format, which is a string of 6 or 7 characters, of which the n0 and ni - 1 will define the size and the type of size respectively, For instance, 26.00t, this value denies we have 26.00 degrees and the character ’t’ means ’temperature. While ’a’ stands for ’acceleration’ and ’h’ for humidity’.

Listing 1: Custom Protocol Trace Example

26.00t38.00h5.12a
22.00t
25.00t39.00h
9.81a

It is obvious we are adding another layer to the communication, which is unnecessary as adding new memory and time synchronization constraints.

At the moment, the team got the first part of the data transfer solved. Now, let’s talk about the I2C Bus communication between the Raspberry PI running ChibiOS, and the Arduino. As we just commented, we proposed to use a master-slave schema and when the Raspberry PI requires new data just it will need to request to the Arduino through the I2C Bus.

We programmed some sketches to test the communication, but the data transfer was failing. First, we thought about the code. Maybe there’s an error. So, we tried some unitary communication tests. But again, they didn’t work properly. Only at the beginning we were receiving data, but till that, no more. Then we started checking the assembly, even presenting it all to the professor in case there is something we couldn’t see.

This was a big mishap. We got all the parts working but not the communication between the Raspberry PI and the Arduino. Also, we were using the ChibiOS Raspberry PI to represent the historical data into the LCD Screen correctly, but using static values though.

Moreover, we commented in class the problem to share it with our partners and the professor. They told us a possible solution, to reset the I2C Bus communication when the action code received were RESET. But, even trying this, it didn’t work. So, we redefined the schema to find out a solution in order to accomplished the user stories, what the client would expect.

Finally, we are using the Arduino for representing the data into the LCD screen. Hence, the Raspberry PI is disabled for non-working purposes. Furthermore, the main idea is to use the

17

MQTT Explorer which is an open-source and free software to allow us to connect to the MQTT Broker and get the data as a detailed and graphical way. It also provides us the fluctuation in the data, connection problems, registration, etc.

Why we bet for this solution? First because of the problems encountered. But also, as it is a cheaper, more vialbe and more versatile way to obtain a Supervision station seeing in real time the values but also using a software to enable historical representation. We strongly recommend to make use of this solution, although it would be better to use the ESP-01 as a WI-FI interface, since it is more simple and more scalable because we just need to use the MQTT Explorer for visualizing. Even using VPN’s we can connect to the several brokers in scaling terms, directly from our home. Nonetheless, there will be always an Arduino board displaying the values at each time, just similar as the Raspberry Pi would do.

The following would be the final wiring schema for our solution:

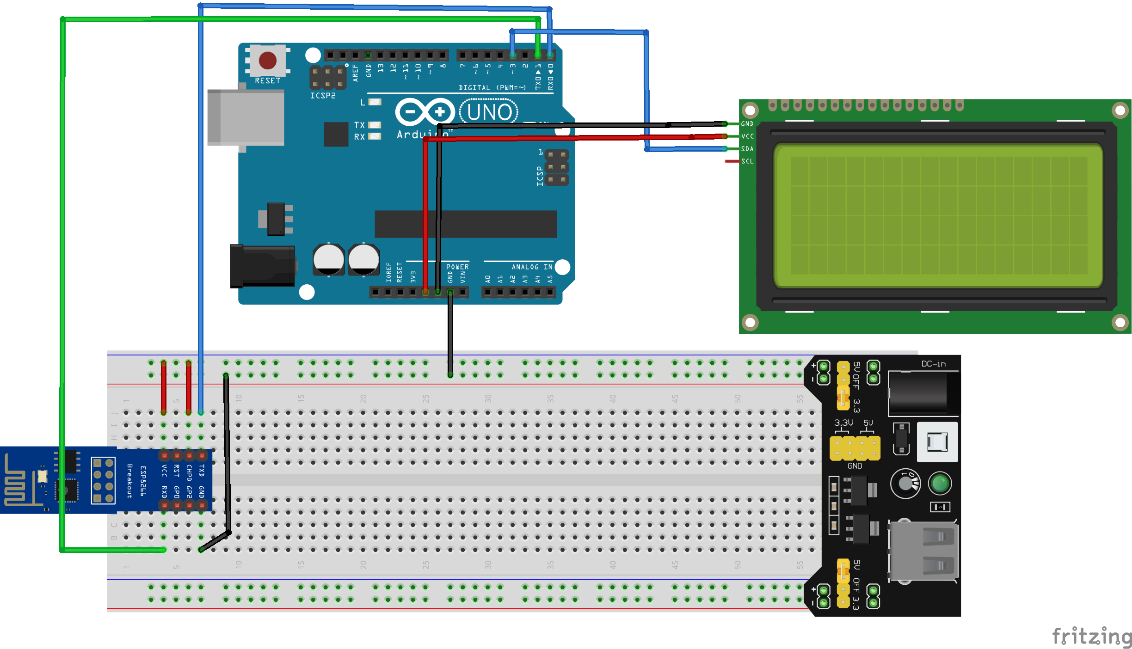
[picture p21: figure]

Figure 12: Solution B Schema

18

## 7 Project Source Code

Our git repository: Wind Turbine Generator Github repository (https://github.com/elskater98/wind_turbine_generator)

19

# Appendices

## A Data Producer 1

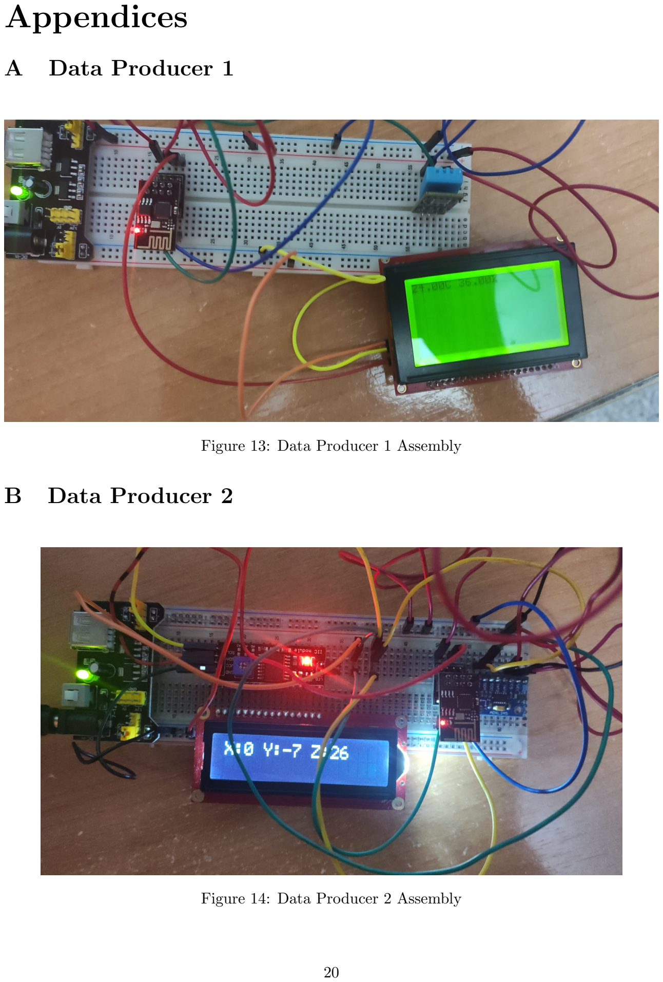
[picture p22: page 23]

Figure 13: Data Producer 1 Assembly

## B Data Producer 2

Figure 14: Data Producer 2 Assembly

20

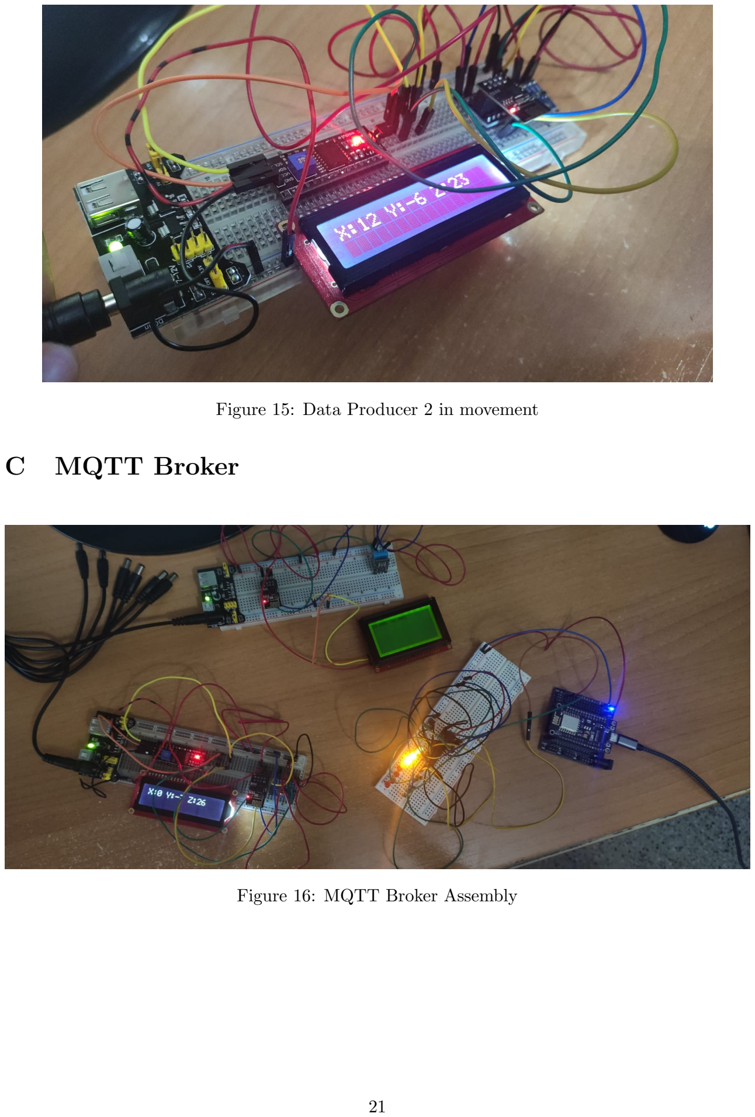
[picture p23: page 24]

Figure 15: Data Producer 2 in movement

## C MQTT Broker

Figure 16: MQTT Broker Assembly

21

## D MQTT Explorer

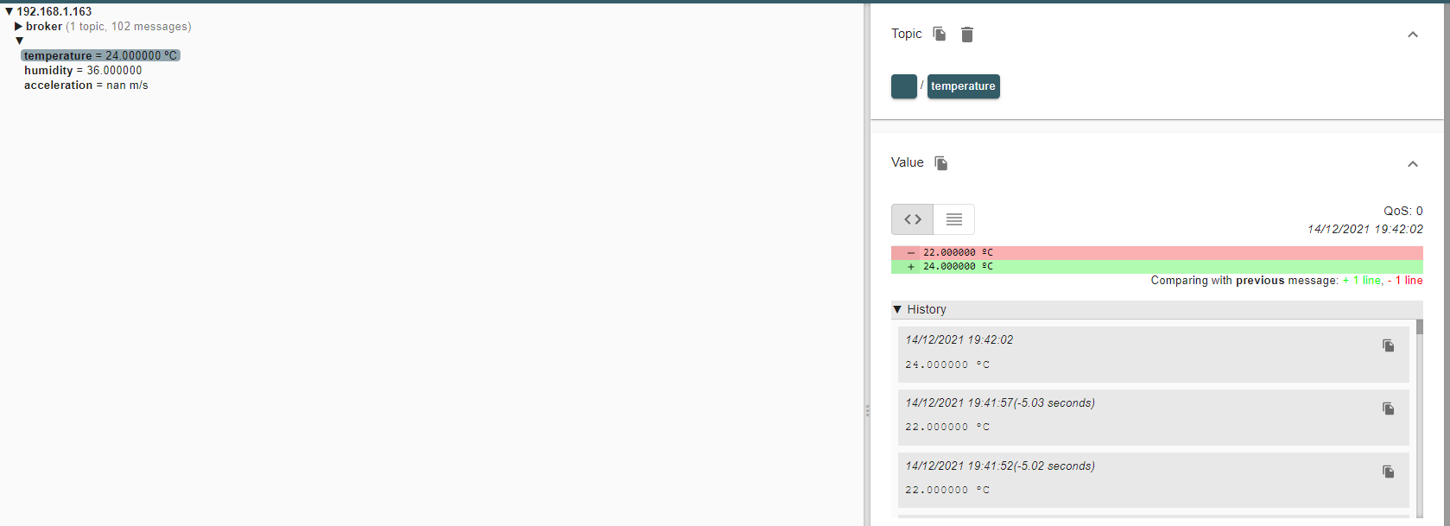
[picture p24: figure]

Figure 17: Temperature Changes


Figure 18: Acceleration Changes

22


Figure 19: Humidity History


Figure 20: Comparison between Solution B and C

23

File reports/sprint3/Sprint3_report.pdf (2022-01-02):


# University of Lleida

## Master’s Degree in Informatics Engineering

## Higher Polythecnic School

# Sprint 3 Documentation

## Ubiquitous Computing and Embedded Systems

Francesc Contreras

Albert P´erez

Marc Visa

December 10, 2021

## Table of contents

1 Introduction | 1
2 Sprint Backlog | 2
3 Sprint 3 Definition | 3
3.1 User stories | | 3
3.2 Story Points | | 3
4 Sprint Review | 4
4.1 Percentage Of Sprint Completion | | 4
4.2 Cummulative flow | | 5
4.3 Burn-down report | | 7
5 Conclusions & Next Sprint | 8

## List of Figures

1 | Wind turbine generator prototype schema | | 1
2 | Cummulative-flow graph | | 5
3 | Cummulative-flow table | | 6
4 | Burn-down graph | | 7

## 1 Introduction

The purpose of this document is to explain how the 3rd sprint of the project has been developed.

First of all, it will introduce the sprint backlog tasks picked from the product backlog of the project, along with the total story points for this sprint. Furthermore, it will be mentioned the sprint goal and the user stories the team has been worked with during the sprint.

Finally, it will show the sprint review, which will contain the percentage of the sprint tasks completion, along with the sprint retrospective and the burn-down and burn-up reports. Addi-tionally, it will define the next sprint as the new modules to be working on, new user stories and the sprint goal.


Figure 1: Wind turbine generator prototype schema

1

## 2 Sprint Backlog

For this sprint, the total story points is 86 points. This may seem too much compared to the previous sprints, but we wanted to get focused on all task related to the Supervision Station as the last step to conclude the project.

In this way, for the last sprint we expected to finish the remaining tasks if any, and work on the integration of all project parts.

Task | Label | Story Point
Prepare Raspberry Pi environment | Learning | 3
Install ChibiOS to Raspberry Pi | Enhancement | 2
Arduino interaction with R.Pi | Enhancement | 13
Connect Raspberry Pi to LCD Screen via serial port | Enhancement | 8
Arduino interaction with ESP-01 | Enhancement | 8
Test Supervision Station | Testing | 13
Data Consumer: Data log and Screen representation | Enhancement | 13
Sprint 3 documentation | Documentation | 13
Supervision Station documentation | Documentation | 13

2

## 3 Sprint 3 Definition

The goal for this sprint is to have a working version of the Supervision Station, which corresponds to the Data Consumer module of the project. The user stories that we have worked on during this sprint are the following:

### 3.1 User stories

1. As a Maintenance manager I would like to represent graphically the obtained sensor data, within the last 24h, in the Supervision Station.
(a) Acceptable Criteria:
i. The Arduino UNO connects to the ESP-01 in order to get the data produced by the Data Producers.
ii. The Raspberry Pi connects to the LCD Screen in order to represent the data from the Data Producers.
iii. The Arduino UNO and the Raspberry Pi are linked by an I2C Bus where the Raspberry Pi will be the master and the Arduino UNO will be the slave.
iv. The ESP-01 receives the data obtained from the MQTT Broker, which has the data from Data Producer 1 and Data Producer 2.
v. We can see the data provided by the MQTT Broker.
(b) Related Task:
i. Supervision Station Development.

The user story corresponds to the work-block named Data Consumer, which components related to are the following:

- ESP-01
- I2C Bus (Raspberry Pi and Arduino communication)
- Arduino UNO
- Raspberry Pi
- LCD Screen

### 3.2 Story Points

Regarding the estimation story point for each task, we would like to remark that we used the Scrum Poker technique via the next webpage https://scrumpoker.online/.

Thus, we assure each of the sprint participants may weigh each task without interference and anonymously. In this way, the influence is none and we obtain realistic story points for each task.

3

## 4 Sprint Review

The goal for this sprint got centered on finishing the Data Consumer module. The Sprint 3 lasted 14 days, from 26 of November to 10 of December.

### 4.1 Percentage Of Sprint Completion

The following are specified the percentage of completion for each task of the Sprint 3 Backlog,
as well as an estimated dedication time in hours for the whole team.
Task | Completion (%) | Team dedication time (h)
Prepare Raspberry Pi Environment | 100 | 1h
Install ChibiOS to Raspberry Pi | 100 | 1h
Arduino interaction with R.Pi | 80 | 3h
Connect Raspberry Pi to LCD Screen via serial port | 100 | 2h
Arduino interaction with ESP-01 | 50 | 2h
Test Supervision Station | 80 | 5h
Data Consumer: Data log and Screen representation | 70 | 4h
Sprint 3 documentation | 100 | 3h
Supervision Station documentation | 25 | 1h

The total dedication time for the Sprint 3 is 22 hours.

The dedication time to this sprint was not as much compared to the others as you may observe. About 1.5 hours per day. Basically, due to some issues encountered which slowed-down the development, and a short vacation period in mid-sprint.

On the other hand, the main purpose of the sprint is accomplished, as we got a working version of the Data Consumer, but waiting to test it all.

The main reason is that we got issues with some failing wires when treating with the SDA connection between the Raspberry Pi and the Arduino when building the component schema for the I2C BUS. And also, with the LCD Screen, the one needed multiple testing because we couldn’t work properly on it as it was failing. Thus, implying not being able to work fairly on the graphics representation, not even see the values received from the Arduino.

Hence, you may observe the ”Arduino interaction with R.Pi” task and the ”Test Supervision Station” task are not completely finished, specifying a symbolic 80 percent.

4

In this way, we should work on finishing and testing the graphics representation on the LCD Screen. Moreover, remains to conclude the Arduino interaction with the ESP to get dynamically the data (this corresponds to the project parts integration), because we could not dedicate so much time due to the problems above mentioned.

### 4.2 Cummulative flow

The cumulative flow diagram is one of the most advanced analytics in Agile project management. It provides a concise visualization of the metrics of flow. It shows you how stable your flow is and helps you understand where to focus on making your process more predictable.


Figure 2: Cummulative-flow graph

This cummulative-flow graph shows how the sprint working lasted. But, you may observe an increase of the tasks on Monday 29. We remark this point, as here is when the sprint was redefined once we studied all the work to face-up.

This sprint has been the hardest in working terms, as new components used, but also the Data Consumer module realizes as the complex part of the whole project which the redefinition suits well as its complexity requires.

5


Figure 3: Cummulative-flow table

Regarding the tasks, at the top there are the four ones already full accomplished, and below the remaining. But taking into account that some are still close to get finished. We only need to solve the issues encountered explained on the 4.1 section.

6

### 4.3 Burn-down report

The burn-down chart shows the amount of work that has been completed in a specific sprint, and the total work remaining. Burn-down charts are used to predict your team’s likelihood of completing their work in the time available.


Figure 4: Burn-down graph

Specially in this graph, highlights the flow in the mid-sprint period. As in the beggining seems there are some closed tasks, as well as in the final period.

But, we wanted to remark this burn-down report the one shows clearly the vacation period in the mid-sprint.

7

## 5 Conclusions & Next Sprint

The team worked well together and the sprint advanced smoothly, not counting the vacation period. Now we shall prepare the last issues and tasks to work on the last sprint and we think that if we keep working as we have done, we shall have the project finished at time.

We should get focused on solving the issues encountered on this sprint to last the remaining tasks and test them all. Mainly the Raspberry Pi and Arduino interaction. And finally, test the whole project parts integration, and realise the final project documentatio.

8

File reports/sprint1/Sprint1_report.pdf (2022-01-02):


# University of Lleida

## Master’s Degree in Informatics Engineering

## Higher Polythecnic School

# Sprint 1 Documentation

## Ubiquitous Computing and Embedded Systems

Francesc Contreras

Albert P´erez

Marc Visa

November 10, 2021

## Table of contents

1 Introduction | 1
2 Product Backlog | 2
3 Sprint 1 Definition | 3
3.1 User stories | | 3
3.2 Sprint 1 Backlog Tasks | | 4
3.3 Story Points | | 4
4 Sprint Review | 5
4.1 Percentage Of Sprint Completion | | 5
4.2 Cummulative flow | | 7
4.3 Burn-down report | | 8

## List of Figures

1 | Wind turbine generator prototype schema | | 1
2 | Sprint 1 Backlog remaining-completed tasks | | 6
3 | Story points and Tasks/Issues percentatge of completion | | 6
4 | Cummulative-flow graph | | 7
5 | Cummulative-flow table | | 7
6 | Burn-down graph | | 8

## 1 Introduction

The purpose of this document is describing the Sprint 1 for the subject Ubiquitous Computing and Embedded Systems project of the University of Lleida (UdL) which is about a desing, test, and development of a Wind Turbine Generator Farm (WTGF).

Subsequently, you will appreciate the product backlog tasks at first instance, as well as the selected ones for this first sprint. Even more, the sprint definition.

Finally, is detailed the spint review as ending part, but also the percentatge of completion.


Figure 1: Wind turbine generator prototype schema

1

## 2 Product Backlog

The Product Backlog Item (PBI) got a total of 122 story points, and is described as follows,

Task | Label | Story Point
Revise Material | Good first issue | 2
Read Documentation ESP-01 | Learning | 3
Read Documentation DHT11 | Learning | 3
Prepare Arduino Environment | Learning | 3
First contact with electronic components | Learning | 8
Read Documentation Accelerometer ADXL345 | Learning | 3
Data Producer 1 development | Enhancement | 8
Data Producer 2 development | Enhancement | 8
Sprint documentaiton | Documentation | 8
Read documentation LCD Screen/Display | Learning | 2
Read documentation I2C Bus Protocol | Learning | 2
Install ChibiOS to Raspberry Pi | Enhancement | 3
Prepare Raspberry Pi environment | Learning | 3
Read documentation about NodeMCU module | Learning | 3
Arduino interaction with ESP-01 | Enhancement | 8
Read documentation MCP23017 | Learning | 3
Test Supervision Station | Testing | 5
Test MQTT Broker | Testing | 5
Test Data Producer 1 | Testing | 5
Test Data Producer 2 | Testing | 5
Data consumer: Data log and Screen representation | Enhancement | 8
Data consumer: Ultrasonic LED bar representation | Enhancement | 8
Arduino interaction with Raspberry Pi | Enhancement | 8

2

## 3 Sprint 1 Definition

This first sprint aims to introduce us to work with electronic components, know them better and how to program it. Basically, to make our first steps into the project, investigate about the its parts and do quick tutorials since we may start working on the Data producers.

### 3.1 User stories

1. As a user I would like to know to obtain the temperature and humidity at the top of the Wind Turbine Generator.
(a) Acceptable Criteria:
i. The Data Producer 1 uses ESP-01 to receive the data from the DHT11 sensor. ii. The ESP-01 sends the data obtained to the LCD Screen to visualize it.
(b) Related Task:
i. Data Producer 1 Development.
2. As a user I would like to know the Wind Turbine Generator tower movement.
(a) Acceptable Criteria:
i. Data Producer 2 uses ESP-01 to receive the data from the ADXL345 sensor. ii. The ESP-01 sends the data obtained to the LCD Display to visualize it.
(b) Related Task:
i. Data Producer 2 Development.

The first user story corresponds to the work-block named Data Producer 1, which components related to are:

- ESP-01
- Temperature and humidity sensor (DHT11)
- LCD Screen

The second user story corresponds to the work-block named Data Producer 2, which components related to are:

- ESP-01
- I2C Bus
- Accelerometer (ADXL345)
- LCD Display

Therefore, the sprint goal for this sprint 1 is to have a working version of the Data Producer 1 and the Data Producer 2 of the project, once we got introduced to work with such components.

3

### 3.2 Sprint 1 Backlog Tasks

As for this first sprint, it has been picked the following tasks:

Task | Label | Story Point
Revise Material | Good first issue | 2
Read documentation ESP-01 | Learning | 3
Read documentation DHT11 | Learning | 3
Prepare Arduino environment | Learning | 3
Frist contact with electronic components | Learning | 8
Read documentation Accelerometer ADXL345 | Learning | 3
Data Producer 1 development | Enhancement | 8
Data Producer 2 development | Enhancement | 8
Sprint documentation | Documentation | 8
Read documentation LCD Screen/Display | Learning | 3
Read documentation I2C Bus Protocol | Learning | 3
Test Data Producer 1 | Testing | 5

The total story points for the Sprint 1 are 55 points.

### 3.3 Story Points

Regarding the estimation story point for each task, we would like to remark that we used the Scrum Poker technique via the next webpage https://scrumpoker.online/.

Thus, we assure each of the sprint participants may ponderate each task without interference and anonymously. In this way, the influence is none and we obtain realistic story points for each task.

4

## 4 Sprint Review

The goal of this sprint was to get introduced to the electronic components as well as how to program them via the Arduino IDE and its libraries. Initiate us to begin the project for the Data producer 1 development and obviously to start working with its components such as the ESP-01, the Humidity sensor, etc.

In addition, we planned this sprint to start doing our first programs to test each of the components that we should use, such as LCD Screen/Display, or even how to work with the WiFi networks, or how the I2C Bus should be programmed.

The Sprint 1 lasted 14 days, from 29th of October to 11th of November.

### 4.1 Percentage Of Sprint Completion

The following are specified the percentage of completion for each task of the Sprint 1 backlog,
as well as an estimated dedication time in hours for the whole team.
Task | Completion (%) | Team dedication time (h)
Revise Material | 100 | 1
Read documentation ESP-01 | 100 | 2
Read documentation DHT11 | 100 | 2
Prepare Arduino environment | 100 | 1
First contact with electronic components | 100 | 4
Read documentation Accelerometer ADXL345 | 100 | 2
Data Producer 1 development | 100 | 5
Data Producer 2 development | 20 | 2
Sprint 1 documentation | 100 | 3
Read documentation LCD Screen/Display | 100 | 2
Read documentation I2C Bus Protocol | 100 | 3
Test Data Producer 1 | 100 | 3

The total dedication time for the Sprint 1 is 30h, which means that for 14 days availables we dedicated 2:15h per day approx.

5


Figure 2: Sprint 1 Backlog remaining-completed tasks

We expected to finally get the two Data Producers as they are similar but we realized that is not as easy as we expected when problems arise. The Data Producer 1 is done, just needs a quick clean of the code and integration with the broker, and the Data Producer 2 we expect to work more on the I2C Bus.

Figure 3: Story points and Tasks/Issues percentatge of completion

Finally, we finish this first sprint with 85% (47/55) of the tasks done, which means that we have to adjust the number of story points for the next sprint.

6


### 4.2 Cummulative flow

The cumulative flow diagram is one of the most advanced analytics in Agile project management. It provides a concise visualization of the metrics of flow. It shows you how stable your flow is and helps you understand where to focus on making your process more predictable.

Figure 4: Cummulative-flow graph

Figure 5: Cummulative-flow table

7

### 4.3 Burn-down report

The burn-down chart shows the amount of work that has been completed in a specific sprint, and the total work remaining. Burn-down charts are used to predict your team’s likelihood of completing their work in the time available.

The team worked well together and the sprint advanced smoothly. Although everything was new to all of us - from working with Scrum to the chosen technologies, we were well integrated, everyone was very supportive and open to researching, learning, and even teaching if necessary.

Lastly, as mentioned we should adjust the next sprint amount of story points, as we couldn’t finish all the tasks in this one, because we just completed 47 from 55 story points. Thus, is still remaingin one task/issue, the Data Producer 2 development.


Figure 6: Burn-down graph

8

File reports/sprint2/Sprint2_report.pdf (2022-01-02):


# University of Lleida

## Master’s Degree in Informatics Engineering

## Higher Polythecnic School

# Sprint 2 Documentation

## Ubiquitous Computing and Embedded Systems

Francesc Contreras

Albert P´erez

Marc Visa

November 10, 2021

## Table of contents

1 Introduction | 1
2 Sprint Backlog | 2
3 Sprint 2 Definition | 3
3.1 User stories | | 3
3.2 Story Points | | 3
4 Sprint Review | 4
4.1 Percentage Of Sprint Completion | | 4
4.2 Cummulative flow | | 5
4.3 Burn-down report | | 6
5 Conclusions and Next Sprint | 7

## List of Figures

1 | Wind turbine generator prototype schema | | 1
2 | Cummulative-flow graph | | 5
3 | Cummulative-flow table | | 5
4 | Burn-down graph | | 6

## 1 Introduction

The purpose of this document is to explain how the 2nd sprint of the project has been developed. First of all, it will introduce the sprint backlog tasks picked from the product backlog of the project, along with the total story points for this sprint. Furthermore, it will mention the sprint goal and the user stories the team has been worked with during the sprint. Finally, it will show the sprint review, which will contain the percentage of the sprint tasks completion, along with the sprint retrospective and the burn-down and burn-up reports. Additionally, it will define the next sprint as the new modules to be working on, new user stories and the sprint goal.


Figure 1: Wind turbine generator prototype schema

1

## 2 Sprint Backlog

For this sprint, the total story points is 69 points.

Task | Label | Story Point
Read documentation MCP23017 | Learning | 3
Test MQTT Broker | Testing | 8
Test Data producer 2 | Testing | 8
Data producer 2 development | Enhancement | 13
MQTT Broker development | Enhancement | 13
Read Documentation about NodeMCU module | Learning | 3
Documentation Sprint 2 | Documentation | 8
Data producer 2 documentation | Documentation | 8
MQTT Broker documentation | Documentation | 5

2

## 3 Sprint 2 Definition

The goal for this sprint is to have a working version of the Data Producer 2 and a working version of the MQTT Broker. The user stories that we have worked with during this sprint are the following:

### 3.1 User stories

1. As a user I would like to know the Wind Turbine Generator tower movement.
(a) Acceptable Criteria:
i. Data Producer 2 uses ESP-01 to receive the data from the ADXL345 sensor. ii. The ESP-01 sends the data obtained to the LCD Display to visualize it.
(b) Related Task:
i. Data Producer 2 Development.
2. As a Broker, I would gather and publish the data using MQTT Protocol.
(a) Acceptable Criteria:
i. The MQTT Broker will receive data from Data Producer 1.
ii. The MQTT Broker will receive data from Data Producer 2.
iii. The MQTT Broker will publish the data gathered from Data Producer 1 and Data Producer 2.
(b) Related Task:
i. MQTT Broker Development.

The first user story corresponds to the work-block named Data Producer 2, which components related to are:
- ESP-01
- I2C Bus
- Accelerometer (ADXL345)
- LCD Display

The second user story corresponds to the work-block named MQTT Broker, which components related to are:
- NodeMCU module
- MCP23017
- Segment LED Bar

### 3.2 Story Points

Regarding the estimation story point for each task, we would like to remark that we used the Scrum Poker technique via the next webpage https://scrumpoker.online/.

Thus, we assure each of the sprint participants may weigh each task without interference and anonymously. In this way, the influence is none and we obtain realistic story points for each task.

3

## 4 Sprint Review

The goal for this sprint was to finish the Data Producer 2 module and the MQTT broker module. We have had a lot of difficulties throughout the sprint. Still, we have accomplished a working version of the Data Producer 2, retrieving and printing data from the accelerometer and a working version of the MQTT broker managing publications and subscriptions.

The Sprint 2 lasted 14 days, from 12 of November to 26 of November.

### 4.1 Percentage Of Sprint Completion

The following are specified the percentage of completion for each task of the Sprint 2 Backlog,
as well as an estimated dedication time in hours for the whole team.
Task | Completion (%) | Team dedication time (h)
Read documentation MCP23017 | 100 | 2h
Test MQTT Broker | 100 | 1h
Test Data producer 2 | 100 | 2h
Data producer 2 development | 100 | 12h
MQTT Broker development | 100 | 8h
Read Documentation about NodeMCU module | 100 | 2h
Documentation Sprint 2 | 100 | 3h
Data producer 2 documentation | 100 | 2h
MQTT Broker documentation | 100 | 3h

The total dedication time for the Sprint 2 is 35h, which means that for 14 days availables we dedicated 2:30h per day approx.

We expected to finally get the Data Producer 2 working well and we accomplished it, but also we achieved a working version of the MQTT Broker, so we finish the second sprint with a 100% of tasks done, which means that we are likely to finish the project on time, since in the last sprint we will work on the third module of the project.

4


### 4.2 Cummulative flow

The cumulative flow diagram is one of the most advanced analytics in Agile project management. It provides a concise visualization of the metrics of flow. It shows you how stable your flow is and helps you understand where to focus on making your process more predictable.

Figure 2: Cummulative-flow graph

Figure 3: Cummulative-flow table

5

### 4.3 Burn-down report

The burn-down chart shows the amount of work that has been completed in a specific sprint, and the total work remaining. Burn-down charts are used to predict your team’s likelihood of completing their work in the time available.


Figure 4: Burn-down graph

6

## 5 Conclusions and Next Sprint

The team worked well together and the sprint advanced smoothly. Now we shall prepare the last issues and tasks to work on the last sprint and we think that if we keep working as we have done, we shall have the project finished by the end of the third sprint.

Therefore, for the last sprint we will focus on the Raspberry PI configuring the environment and installing the ChibiOS, but also on the Arduino, at first, working on the interaction with the corresponding ESP-01, and finally, with the Raspberry PI.

Thus, for the last sprint, we only need to adjust all the components to work together following the project schema. And make tests, for sure.

7

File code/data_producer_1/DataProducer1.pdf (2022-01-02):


# University of Lleida

## Master’s Degree in Informatics Engineering

## Higher Polythecnic School

# Data Producer 1

## Ubiquitous Computing and Embedded Systems

Francesc Contreras

Albert P´erez

Marc Visa

November 10, 2021

## Table of contents

1 Introduction | 1
2 Environment | 1
2.1 Material required | | 3
3 Development | 4
3.1 Hardware | | 4
3.2 Software | | 5
4 Code repository | 8

## List of Figures

1 | Installing the DHT sensor library for ESPx from the Arduino Manage Libraries. | 2
2 | Installing the Adafruit Unified Sensor from the Arduino Manage Libraries | | 2
3 | Installing the ESP8266 Board from the Arduino Boards Manager | | 2
4 | Data Producer 1 Diagram | | 4
5 | Data Producer 1 Assembly | | 5

## 1 Introduction

The purpose of this document is to explain the Data Producer 1 development for the Sprint 1 of the project.

We shall introduce all the steps and software we have used when developing the it and showing images as a real example for detailed explanation.

## 2 Environment

At first, these are the steps for installing the libraries and setting up the Arduino IDE to get started for the Data Producer 1 development:

1. Install Arduino IDE v.1.8.16. (https://www.arduino.cc/en/software)
2. Install driver (http://www.wch.cn/download/CH341SER_EXE.html) for USB adapter to ESP-01 and switch the interrupter to PROG mode.
3. Install ESP8266 Board from Boards Manager from Arduino IDE.
4. Install the following libraries from the Manage Libraries of Arduino IDE:
(a) DHT 1
library by Adafruit.
(b) Adafruit Unified Sensor by Adafruit.
5. Install the following libraries from GitHub: (These libraries should be added to the Arduino/libraries folder):
(a) PubSubClient² (https://github.com/knolleary/pubsubclient)
6. Connect the ESP-01³ along with the USB adapter to your machine.
7. Code the program for the ESP-01 and DHT11.

1Temperature and humidity sensor
2MQTT Library
3Low-cost WiFi microchip with built-in TCP/IP networking software, and microcontroller capability

1


Figure 1: Installing the DHT sensor library for ESPx from the Arduino Manage Libraries.


Figure 2: Installing the Adafruit Unified Sensor from the Arduino Manage Libraries.


Figure 3: Installing the ESP8266 Board from the Arduino Boards Manager.

### 2.1 Material required

Subsequently, you will find all the required components for the Data Producer 1, and a short explanatory description for those not so common.

- ESP-01 (3.3 V): is a Wi-Fi module that allows microcontrollers access to a Wi-Fi network.
- Breadboard: A board, having a matrix of small holes to which components may be attached without solder.
- LCD Screen (5V): is a flat-panel display or other electronically modulated optical device that uses the light-modulating properties of liquid crystals combined with polarizers.
- DHT11 (3.3V): is a basic, ultra low-cost digital temperature and humidity sensor.
- VCC Protoboard adapter (3.3V, 5V)
- ESP Programmer module
- Wires

## 3 Development

Regards the development, this is based on two parts, the first one realated to work directly with the electronic components, and the second by programming the arduino sketch.

The following sections shows you how the electronic schema is in real, as well as how finally we got the visualization of the temperature and the humidity by two different ways.

Moreover, there is the code shown below, but also you may consult the github repository of the project, the one is specified subsequently.

### 3.1 Hardware

### 3.1.1 Diagram


Figure 4: Data Producer 1 Diagram

Pay Attention!, in our LCD Screen we don’t have SDA and SCL connections, we have RX and TX, then our RX is SDA and TX is SCL in the Figure 4.

4

### 3.1.2 Assembly


Figure 5: Data Producer 1 Assembly

### 3.2 Software

// Import required libraries #include <Arduino.h>
#include <ESP8266WiFi.h>

#include <Adafruit_Sensor.h> #include <DHT.h>

//MQTT Pub
#include <PubSubClient.h>

// Replace with your network credentials const char* ssid = "-";
const char* password = "-";

// DHT11
#define DHTPIN 2 | // Digital pin connected to the DHT sensor

#define DHTTYPE | DHT11 | // DHT 11

DHT dht(DHTPIN, DHTTYPE);

float t = 0.0;
float h = 0.0;

// MQTT

const char* mqtt_server = "192.168.1.163"; // MQTT BROKER IP WiFiClient espClient;

5

PubSubClient client(espClient);

#define MSG_BUFFER_SIZE (50)

char msg[MSG_BUFFER_SIZE];

void callback(char* topic, byte* payload, unsigned int length) { /*Serial.print("Message arrived [");
Serial.print(topic);
Serial.print("] ");
for (int i=0;i<length;i++) { Serial.print((char)payload[i]); }
Serial.println();*/
}

void reconnect() {
// Loop until we’re reconnected
while (!client.connected()) { Serial.print("Attempting MQTT connection..."); // Create a random client ID
String clientId = "DataProducer1";
clientId += String(random(0xffff), HEX);
// Attempt to connect
if (client.connect(clientId.c_str())) { Serial.println("connected");
// Once connected, publish an announcement... client.publish("outTopic", "connected");
// ... and resubscribe
client.subscribe("#");
} else {
Serial.print("failed, rc="); Serial.print(client.state()); Serial.println(" try again in 5 seconds"); // Wait 5 seconds before retrying delay(5000);
}
}
}

void setup(){

Serial.begin(115200);

// Connect to Wi-Fi
WiFi.begin(ssid, password); Serial.println("Connecting to WiFi");

while (WiFi.status() != WL_CONNECTED) { delay(1000);
Serial.println(".");
}

// Print ESP8266 Local IP Address

6

Serial.println(WiFi.localIP());

dht.begin();

client.setServer(mqtt_server, 1883); client.setCallback(callback);
}

void clean_screen()
{
Serial.write(0x7C);
Serial.write(0x00);
}

void loop(){
clean_screen();

// MQTT
if (!client.connected()) { reconnect();
}
client.loop();

// Temperature
float newT = dht.readTemperature();
if (isnan(newT)) {
Serial.println("Failed to read from DHT sensor!"); }
else {
t = newT;
String outStringT = (String) t+"C "; Serial.print(outStringT);
snprintf (msg, MSG_BUFFER_SIZE, "%f C", t); client.publish("/temperature", msg);
}

// Humidity
float newH = dht.readHumidity();
// if humidity read failed, don’t change h value if (isnan(newH)) {
Serial.println("Failed to read from DHT sensor!"); }
else {
h = newH;
String outStringH = (String) h+"%"; Serial.print(outStringH);
snprintf (msg, MSG_BUFFER_SIZE, "%f ", h); client.publish("/humidity", msg);
}

delay(5000);
}

7

## 4 Code repository

Wind Turbine Generator Github repository (https://github.com/elskater98/wind_turbine_generator)

## References

[1] ESP8266 DHT11/DHT22 Temperature and Humidity Web Server with Arduino IDE (https://randomnerdtutorials.com/esp8266-dht11dht22-temperature-and-humidity-web-server-with-arduino-ide/)

8

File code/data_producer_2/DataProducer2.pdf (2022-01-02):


# University of Lleida

## Master’s Degree in Informatics Engineering

## Higher Polythecnic School

# Data Producer 2

## Ubiquitous Computing and Embedded Systems

Francesc Contreras

Albert P´erez

Marc Visa

November 10, 2021

## Table of contents

1 Introduction | 1
2 Environment | 1
2.1 Material required | | 2
3 Development | 2
3.1 Hardware | | 3
3.2 Software | | 5
4 Code repository | 8

## List of Figures

1 | | | 3
2 | Data Producer 2 Assembly | | 3
3 | Data Producer 2 in movement | | 4

## 1 Introduction

The purpose of this document is to explain the Data Producer 2 development for the Sprint 1 and 2 of the project.

We shall introduce all the steps and software we have used when developing it and showing images as a real example for detailed explanation.

## 2 Environment

At first, these are the steps for installing the libraries and setting up the Arduino IDE to get started for the Data Producer 2 development:

1. Install Arduino IDE. (https://www.arduino.cc/en/software)
2. Install driver (http://www.wch.cn/download/CH341SER_EXE.html) for USB adapter to ESP-01 in PROG mode.
3. Install ESP8266 Board from Boards Manager from Arduino IDE.
4. Install the following libraries from the Manage Libraries of Arduino IDE:
(a) SparkFun ADXL345
(b) Adafruit Unified Sensor by Adafruit.
5. Install the following libraries from GitHub: (These libraries should be added to the Arduino/libraries folder):
(a) LiquidCrystal I2C¹ (https://github.com/johnrickman/LiquidCrystal_I2C)
(b) PubSubClient² (https://github.com/knolleary/pubsubclient)
6. Connect the ESP-01³ along with the USB adapter to your machine.
7. Code the program for the ESP-01.

1We use this custom library, because it correct the bugs related to ESP-01 using Arduino IDE v 1.8.16 2MQTT Library
3Low-cost WiFi microchip with built-in TCP/IP networking software, and microcontroller capability

1

### 2.1 Material required

Subsequently, you will find all the required components for the Data Producer 2, and a short description for those not so common.

- ESP-01 (3.3 V): is a Wi-Fi module that allows micro-controllers access to a Wi-Fi network.
- Breadboard: A board, having a matrix of small holes to which components may be attached without solder.
- LCD Display (5V): is a flat-panel display or other electronically modulated optical device that uses the light-modulating properties of liquid crystals combined with polarizers.
- ADXL345 (3.3V): is an component that measures the acceleratometer, it allows us to use I2C or SPI .
- VCC Protoboard adapter (3.3V, 5V)
- ESP Programmer module
- I2C Bus: is an component that extends I2C Bus and allows us to use with another components such as LCD Display.
- Wires

## 3 Development

Regards the development, this is based on two parts, the first one realated to work directly with the electronic components, and the second by programming the arduino sketch.

The following sections shows you how the electronic schema is in real, as well as how finally we got the visualization of the acceleration.

Moreover, there is the code shown below, but also you may consult the GitHub repository of the project, the one is specified subsequently.

2


### 3.1 Hardware

### 3.1.1 Diagram schema

Figure 1

### 3.1.2 Assembly

Figure 2: Data Producer 2 Assembly

3


Figure 3: Data Producer 2 in movement

4

### 3.2 Software

// Import required libraries #include <Arduino.h>
#include <ESP8266WiFi.h>

//#include <SoftwareSerial.h>

#include <Wire.h>

#include <LiquidCrystal_I2C.h>

#include <SPI.h>

#include <SparkFun_ADXL345.h>

//MQTT Pub
#include <PubSubClient.h>

// Replace with your network credentials const char* ssid = "-";
const char* password = "-";

LiquidCrystal_I2C lcd(0x27,16,2);

ADXL345 adxl = ADXL345();

// MQTT

const char* mqtt_server = "192.168.1.163"; //MQTT BROKER IP WiFiClient espClient;
PubSubClient client(espClient);

#define MSG_BUFFER_SIZE (50)

char msg[MSG_BUFFER_SIZE];

void callback(char* topic, byte* payload, unsigned int length) { /*Serial.print("Message arrived [");
Serial.print(topic);
Serial.print("] ");
for (int i=0;i<length;i++) { Serial.print((char)payload[i]); }
Serial.println();*/
}

void reconnect() {
// Loop until we’re reconnected
while (!client.connected()) { Serial.print("Attempting MQTT connection..."); // Create a random client ID
String clientId = "DataProducer2";
clientId += String(random(0xffff), HEX);
// Attempt to connect

5

if (client.connect(clientId.c_str())) { Serial.println("connected");
// Once connected, publish an announcement... client.publish("outTopic", "connected");
// ... and resubscribe
client.subscribe("#");
} else {
Serial.print("failed, rc="); Serial.print(client.state()); Serial.println(" try again in 5 seconds"); // Wait 5 seconds before retrying delay(5000);
}
}
}

void setup(){
// Serial port for debugging purposes Serial.begin(115200);

// WIFI
// Connect to Wi-Fi
WiFi.begin(ssid, password);

Serial.println("Connecting to WiFi"); while (WiFi.status() != WL_CONNECTED) { delay(1000);
Serial.println(".");
}

// Print ESP8266 Local IP Address Serial.println(WiFi.localIP());

Wire.begin(0, 2); // SDA and SCL // ACCELEROMETER
adxl.powerOn();

adxl.setRangeSetting(16); //Definir el rango, valores 2, 4, 8 o 16

// DISPLAY
lcd.init();
lcd.backlight();

// MQTT
client.setServer(mqtt_server, 1883); client.setCallback(callback);
}

void loop(){
// MQTT
if (!client.connected()) { reconnect();
}

6

client.loop();

int x, y, z;
adxl.readAccel(&x, &y, &z);
lcd.clear();

lcd.print((String)"X:"+x+" Y:"+y+" Z:"+z);

snprintf (msg, MSG_BUFFER_SIZE, "%f m/s",sqrt(x^2+y^2+z^2)); client.publish("/acceleration", msg);
delay(5000);
}

7

## 4 Code repository

Wind Turbine Generator Github repository (https://github.com/elskater98/wind_turbine_generator)

## References

[1] ADXL345 Tutorial (https://www.luisllamas.es/arduino-acelerometro-adxl345/)

8

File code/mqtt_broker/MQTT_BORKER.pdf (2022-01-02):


# University of Lleida

## Master’s Degree in Informatics Engineering

## Higher Polythecnic School

# MQTT Broker

## Ubiquitous Computing and Embedded Systems

Francesc Contreras

Albert P´erez

Marc Visa

November 10, 2021

## Table of contents

1 Introduction | 1
2 Environment | 1
2.1 Material required | | 2
3 Development | 2
3.1 Hardware | | 6
3.2 Testing | | 6
3.3 Software | | 10
4 Code repository | 12

## List of Figures

1 | MCP23017 Schema | | 2
2 | MQTT Broker Diagram | | 6
3 | MQTT Explorer for Data Producer 1 | | 7
4 | MQTT Explorer for Data Producer 1 History and values | | 7
5 | MQTT Explorer History chart | | 8
6 | MQTT Explorer for Data Producer 2 | | 8
7 | MQTT Explorer for both Data Producers | | 9

## 1 Introduction

The purpose of this document is to explain the MQTT Broker development for the second sprint of the project.

We shall introduce all the steps and software we have used when developing it and showing images as a real example for detailed explanation.

## 2 Environment

Firstly, these are the steps for installing the libraries and setting up the Arduino IDE to get started for the MQTT Broker development:

1. Install ESP8266 Board from Boards Manager from Arduino IDE.
2. Install the following libraries from the Manager Libraries of Arduino IDE:
(a) Adafruit MCP23017
(b) Adafruit Unified Sensor by Adafruit.
3. Install the following libraries from GitHub: (These libraries should be added to the Arduino/libraries folder):
(a) uMQTTBroker (https://github.com/martin-ger/uMQTTBroker)
4. Select NodeMCU v1.0 as compilation environment.
5. Connect the NodeMCU v1.0 along with the micro-USB adapter to your machine.
6. Code the program for NodeMCU v1.0.

1

### 2.1 Material required

Subsequently, you will find all the required components for the Data Producer 2, and a short description for those uncommon ones.

- NodeMCU: open source firmware for which open source prototyping board designs are available. The firmware is based on the eLua project, and built on the Espressif Non-OS SDK for ESP8266. Initially included firmware which runs on the ESP8266 Wi-Fi SoC from Espressif Systems, and hardware which was based on the ESP-12 module.[6][7] Later, support for the ESP32 32-bit MCU was added.
- Breadboard: A board, having a matrix of small holes to which components may be attached without solder.
- MCP23017: Component that measures the accelerometer sensor, it allows us to use I2C or SPI. It is a port expander that gives you virtually identical PORTS compared to standard micro-controllers e.g. Arduino or PIC devices and it even includes interrupts. It gives you an extra 16 I/O pins using an I2C interface as well as comprehensive interrupt control.
- Wires
- LED

## 3 Development

As regards the development, this is based on two parts, the first one related to work directly with the electronic components, and the second by programming the arduino sketch.

The following sections shows you how the electronic schema is in real, as well as how finally we got the visualization of the acceleration.

Moreover, there is the code shown below, but also you may consult the GitHub repository of the project, the one is specified subsequently. So each led represents the number of subscribers that are connected to the broker. The two tables that are following are the MCP23017 GPIO mapping and the NodeMCU and MCP23017 pins mapping, respectively.


Figure 1: MCP23017 Schema

2

Pin Name | Physical PIN | Adafruit PIN | Function
GPB0 | 1 | 8 | Bidirectional I/O pin.
GPB1 | 2 | 9 | Bidirectional I/O pin.
GPB2 | 3 | 10 | Bidirectional I/O pin.
GPB3 | 4 | 11 | Bidirectional I/O pin.
GPB4 | 5 | 12 | Bidirectional I/O pin.
GPB5 | 6 | 13 | Bidirectional I/O pin.
GPB6 | 7 | 14 | Bidirectional I/O pin.
GPB7 | 8 | 15 | Bidirectional I/O pin.
VDD | 9 | NA | Power
VSS | 10 | NA | Ground
NC | 11 | NA | Not connected
SCL | 12 | NA | I Serial clock input
SDA | 13 | NA | I/O Serial data I/O
NC | 14 | NA | Not connected
A0 | 15 | NA | Hardware address pin. Must be externally biased.
A1 | 16 | NA | Hardware address pin. Must be externally biased.
A2 | 17 | NA | Hardware address pin. Must be externally biased.
RESET | 18 | NA | Hardware reset. Must be externally biased.
INTB | 19 | NA | Interrupt output for PORTB.
INTA | 20 | NA | Interrupt output for PORTA.
GPA0 | 21 | 0 | Bidirectional I/O pin.
GPA1 | 22 | 1 | Bidirectional I/O pin.
GPA2 | 23 | 2 | Bidirectional I/O pin.
GPA3 | 24 | 3 | Bidirectional I/O pin.
GPA4 | 25 | 4 | Bidirectional I/O pin.
GPA5 | 26 | 5 | Bidirectional I/O pin.
GPA6 | 27 | 6 | Bidirectional I/O pin.
GPA7 | 28 | 7 | Bidirectional I/O pin.

Table 1: MCP23017 pin descriptions

3

Adafruit PIN | Pin Name | Physical Pin
0 | GPA0 | 21
1 | GPA1 | 22
2 | GPA2 | 23
3 | GPA3 | 24
4 | GPA4 | 25
5 | GPA5 | 26
6 | GPA6 | 27
7 | GPA7 | 28
8 | GPB0 | 1
9 | GPB1 | 2
10 | GPB2 | 3
11 | GPB3 | 4
12 | GPB4 | 5
13 | GPB5 | 6
14 | GPB6 | 7
15 | GPB7 | 8

Table 2: Adafruit MCP23017 pin mapping

4

MCU Pin | MCU Pin Name | MCP23017 Pin | MCP23017 Pin Name
17 | D1 | 12 | SCL
18 | D2 | 13 | SDA
21 | 3V3 | 18 | Reset
21 | 3V3 | 9 | VDD
22 | GND | 10 | VSS
22 | GND | 15 | A0
22 | GND | 16 | A1
22 | GND | 17 | A2

Table 3: Our schema

5

### 3.1 Hardware

### 3.1.1 Diagram schema


Figure 2: MQTT Broker Diagram

### 3.2 Testing

For the testing process of the development, it has been used the MQTT Explorer in order to check if there were real connection with the broker and also check if the Data Producers sent the data correctly. Additionally, as it can be observed in the figure, when testing if a client was connected it is coded as the green Led is lighted if one client was connected. If two clients were connected, the green one and the first yellow one were lighted and so in succession.

### 3.2.1 Data Producer 1

In this picture, we can see the number of connections that our MQTT Broker has, along with the retrieved data from temperature and humidity sensor

6


Figure 3: MQTT Explorer for Data Producer 1

For this second picture, we can see in the right side of the Explorer some information regarding the topics, values of the MQTT Broker. In this case, we have two topics, the humidity topic and the temperature topic. As for the values we can observe a history of the temperature and humidity sensor values, which the broker has retrieved


Figure 4: MQTT Explorer for Data Producer 1 History and values

Finally, in this picture we can observe that the Explorer shows us some chart that renders the high and low peaks, which represents the data retrieving period as a time-series.

7


Figure 5: MQTT Explorer History chart

### 3.2.2 Data Producer 2

For the Data Producer 2 in the MQTT Broker, it is defined the acceleration topic, which the accelerometer publishes the data and the Broker retrieves it.


Figure 6: MQTT Explorer for Data Producer 2

8

### 3.2.3 All

In this final picture, we can observe both Data Producers that are publishing data in the three mentioned topics previously (humidity, temperature, acceleration) and the MQTT is retrieving all the data by the topics and shows the values of the respective topics on the left part of the screen of the MQTT Explorer.


Figure 7: MQTT Explorer for both Data Producers

9

### 3.3 Software

// Import required libraries #include <Arduino.h>
#include <ESP8266WiFi.h>

// MCP23017 Lib
#include <Wire.h>

#include <Adafruit_MCP23017.h>

// MQTT Broker
#include "uMQTTBroker.h"

uMQTTBroker myBroker;

// Replace with your network credentials const char* ssid = "-";
const char* password = "-";

// Instance of MCP23017 library Adafruit_MCP23017 mcp;

int counter = 0;
void setup(){

Serial.begin(115200);

// Connect to Wi-Fi
WiFi.begin(ssid, password); Serial.println("Connecting to WiFi");

while (WiFi.status() != WL_CONNECTED) { delay(1000);
Serial.println(".");
}

// Print ESP8266 Local IP Address Serial.println(WiFi.localIP());

//MCP
mcp.begin(); //0x20

// Init LED (RED = [7,4], Yellow = [3,1], Green=[0]) for(int i=0; i<8;i++){
mcp.pinMode(i, OUTPUT);
}

//Serial.println("Starting MQTT broker"); myBroker.init();
myBroker.subscribe("#"); // all topics myBroker.subscribe("/temperature"); myBroker.subscribe("/humidity"); myBroker.subscribe("/acceleration"); }

10

void loop(){

delay(5000); // 5 seconds

myBroker.publish("broker/connections", (String)myBroker.getClientCount());

// MQTT Broker LED BAR

Serial.println((String)"Current Clients: " + myBroker.getClientCount());

// Check if we have clients
if(myBroker.getClientCount() > 0){
for(int i=0; i < myBroker.getClientCount();i++){ if(i<8){
mcp.digitalWrite(i, HIGH);
}
}
}else{
for(int i = 0; i < 8 ;i++){ mcp.digitalWrite(i, LOW);
}
}
}

11

## 4 Code repository

Wind Turbine Generator Github repository (https://github.com/elskater98/wind_turbine_generator)

## References

[1] MCP23017 Tutorial (https://medium.com/@wilko.vehreke/more-gpios-for-the-esp8266-with-the-mcp23017-b89f5e15cde3)
[2] MCP23017 Diagram (https://z-uno.z-wave.me/examples/mcp23017-port-expander/)

12

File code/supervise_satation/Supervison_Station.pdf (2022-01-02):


# University of Lleida

## Master’s Degree in Informatics Engineering

## Higher Polythecnic School

# Supervision Station

## Ubiquitous Computing and Embedded Systems

Francesc Contreras

Albert P´erez

Marc Visa

November 10, 2021

## Table of contents

1 Introduction | 1
2 Environment | 2
2.1 ESP-01 | | 2
2.2 Arduino Uno | | 2
2.3 Raspberry Pi | | 3
2.4 Material required | | 4
3 Development | 5
3.1 Software | | 8
4 Code repository | 12

## List of Figures

1 | Solution A Schema | | 5
2 | Solution B Schema | | 7

## 1 Introduction

The purpose of this document is to report the Supervision Station development for the third sprint of the project which corresponds to the Data Consumer. We shall introduce all the steps and software we have used when developing it and showing images as a real example for detailed explanation.

The document is structured on introducing, at first, the requirements and materials needed to accomplished the development of the Supervision Station. But the key section remarks on explaining the criteria and decisions taken while developing.

So, in the development section, the idea is to focused not only on detailing the final solution but also to care about all the steps and decisions taken during the process.

In this manner, it makes sense the final solution when specifying its underground.

1

## 2 Environment

In this section, we will introduce you to preparing the environment to work and program the supervision station, and also for each of the main components involved is specified specific criteria to develop their functionalities.

Firstly, to work with the Arduino UNO and ESP-01 components we should,

1. Install Arduino IDE. (https://www.arduino.cc/en/software)

Used to program the sketches, from which the components are based on to develop the supervision station functionality.

Subsequently, there are specific remarks for each of these components regarding the Arduino IDE dependencies such as libraries used, and some criteria about working with them.

### 2.1 ESP-01

1. Arduino IDE dependencies:
- Install driver (http://www.wch.cn/download/CH341SER_EXE.html) for USB adapter to ESP-01¹
in PROG mode.
- Install ESP8266 Board from the Arduino IDE Boards Manager.
- Install the following libraries from GitHub: (These libraries should be added to the Arduino/libraries folder):
(a) PubSubClient² (https://github.com/knolleary/pubsubclient)
2. Use a USB adapter to connect the ESP-01 to your machine in order to set up the sketch programmed.
3. Code the program/sketch.

### 2.2 Arduino Uno

1. Connect the Arduino Uno to your machine via USB to set up the sketch.
2. Code the program/sketch.

1Low-cost WiFi microchip with built-in TCP/IP networking software, and microcontroller capability 2MQTT Library

2

Then, the raspberry Pi is quite different as actually we were using a Linux distribution (Ubuntu), not an IDE, to develop its functionality. In this way, you will need a machine running Ubuntu if following our own way to work. The following are specified the dependencies and criteria to be taken into account.

### 2.3 Raspberry Pi

1. Install Developer ARM Toolchain
(a) Ubuntu:

sudo apt-get install gcc-arm-none-eabi

(b) Windows 10: gcc-arm-none-eabi (https://developer.arm.com/tools-and-software/open-source-software/developer-tools/gnu-toolchain/gnu-rm/downloads)
2. Download ChibiOS-RPi (https://github.com/steve-bate/Chibios-Rpi) for Raspberry Pi
3. Prepare SD-Card
(a) bootcode.bin (https://github.com/elskater98/wind_turbine_generator/blob/master/code/supervise_satation/chibiOS/bootcode.bin)
(b) start.elf (https://github.com/elskater98/wind_turbine_generator/blob/master/code/supervise_satation/chibiOS/start.elf)
4. Check arm-none-eabi-gcc

arm-none-eabi-gcc --version

5. Compile your code using ”make” command.
6. Rename the file build/ch.bin to kernel.img
7. Load kernel.img to SD-Card

3

### 2.4 Material required

Next, you will find all the required components for the Supervision Station, and a brief description for those uncommon ones.

- Raspberry Pi: a low cost, credit-card sized computer that plugs into a computer monitor or TV, and uses a standard keyboard and mouse. It is a capable little device that enables people of all ages to explore computing, and to learn how to program in languages like Scratch and Python. It’s capable of doing everything you’d expect a desktop computer to do, from browsing the internet and playing high-definition video, to making spreadsheets, word-processing, and playing games.
- ChibiOS/RT: a compact and fast real-time operating system supporting multiple archi-tectures and released under a mix of the GNU General Public License version 3 (GPL3) and the Apache License 2.0 (depending on module).
- Arduino UNO: a microcontroller board based on the ATmega328P (datasheet). It has 14 digital input/output pins (of which 6 can be used as PWM outputs), 6 analog inputs, a 16 MHz ceramic resonator (CSTCE16M0V53-R0), a USB connection, a power jack, an ICSP header and a reset button. It contains everything needed to support the microcontroller; simply connect it to a computer with a USB cable or power it with a AC-to-DC adapter or battery to get started.. You can tinker with your Uno without worrying too much about doing something wrong, worst case scenario you can replace the chip for a few dollars and start over again.
- ESP-01: is a Wi-Fi module that allows microcontrollers access to a Wi-Fi network.
- LCD Serial Screen: is a flat-panel display or other electronically modulated optical device that uses the light-modulating properties of liquid crystals combined with polarizers.
- Breadboard: a board having a matrix of small holes to which components may be attached without solder.
- ESP Programmer module
- Wires

4
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

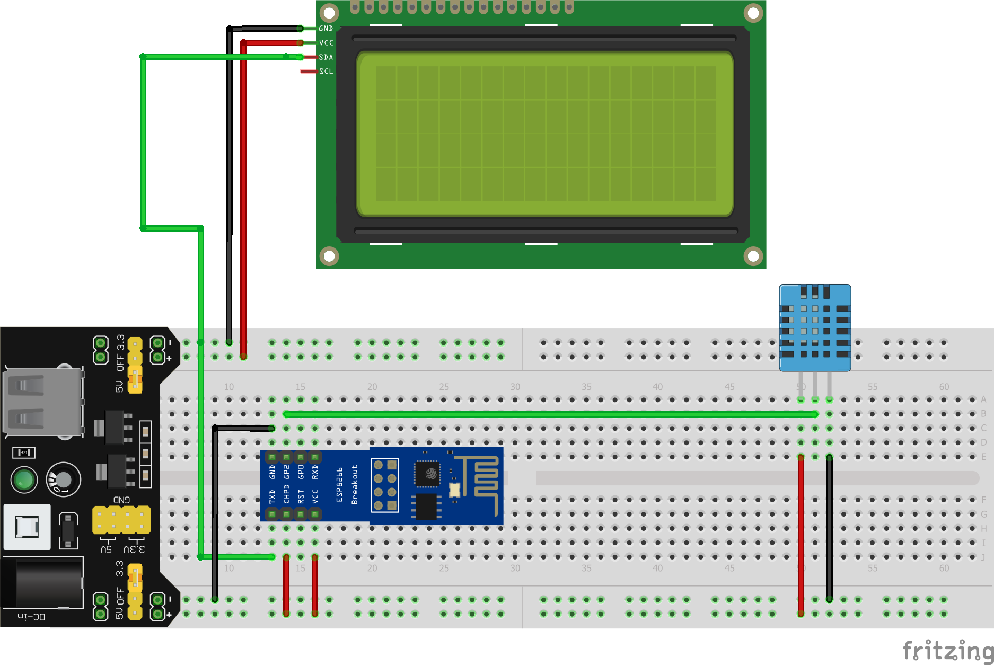
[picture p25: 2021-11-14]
schemas/DataProducer_1/DataProducer1.png

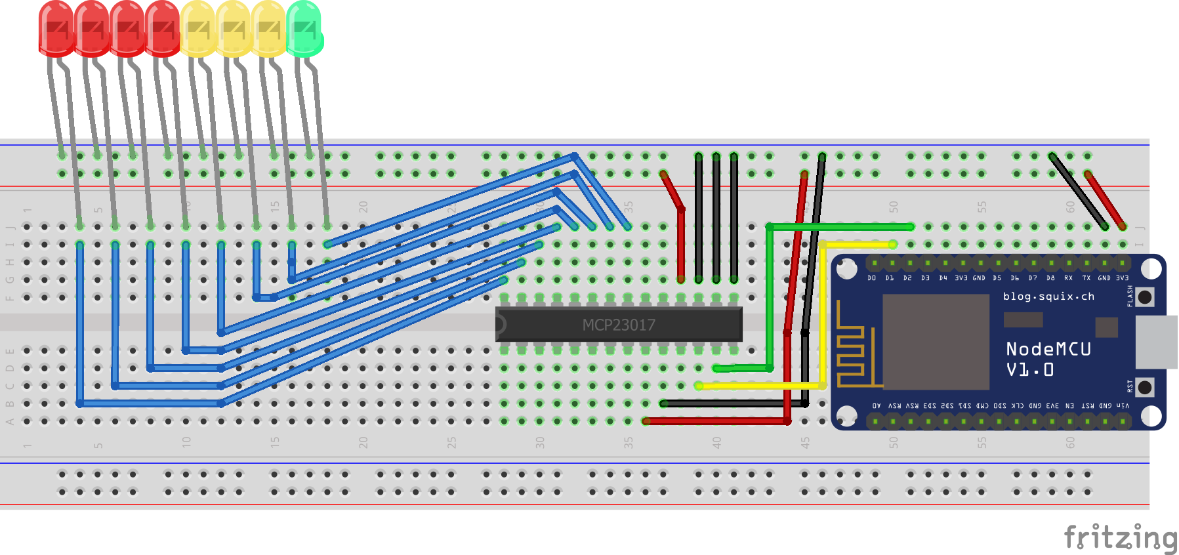
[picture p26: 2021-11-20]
schemas/MQTT_Broker/NodeMCU+MCP23017.png

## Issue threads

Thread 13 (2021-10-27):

Data Producer 2 development

mvp17, 2021-10-27:
- [x] Connection between ESP with I2C Bus
- [ ] Connection between I2C Bus with Accelerometer
- [x] Connection between I2C with LCD Display
- [ ] Retrieve data from accelerometer
- [ ] Print retrieved data to LCD Display

Closed 2021-11-17.

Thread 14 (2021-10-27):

Data Consumer: Data log and Screen representation

mvp17, 2021-10-27:

elskater98, 2021-12-16:
We define alternative solution, because Raspberry Pi didn't work.

Closed 2021-12-16.

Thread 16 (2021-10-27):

Arduino interaction with R.Pi

mvp17, 2021-10-27:
- [ ] Connection between Arduino and I2C Bus
- [ ] Connection between Raspberry PI with I2C Bus

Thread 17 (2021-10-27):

MQTT Broker Development

elskater98, 2021-10-27:
- [x] Connection between NodeMCU with I2C
- [x] Connection between MCP23017 with I2C
- [x] Connection between MCP23017 with Segment Led bar
- [x] Add Broker
- [x] Add Publisher to DP1
- [x] Add Publisher to DP2

Closed 2021-11-20.

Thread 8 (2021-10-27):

Test Supervision Station

elskater98, 2021-10-27:
- [ ] Test the connection between Arduino and the ESP-01
- [ ] Test the connection between Arduino and I2C Bus
- [ ] Test the connection between Raspberry Pi and I2C Bus
- [ ] Test the connection between Raspberry Pi and LCD Screen

Closed 2022-01-02.

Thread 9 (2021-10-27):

Test MQTT Broker

elskater98, 2021-10-27:
- [ ] Test connection NodeMCU and i2c
- [ ] Test connection MCP23017 with i2c
- [ ] Test connection MCP with segment led bar

Closed 2021-11-20.

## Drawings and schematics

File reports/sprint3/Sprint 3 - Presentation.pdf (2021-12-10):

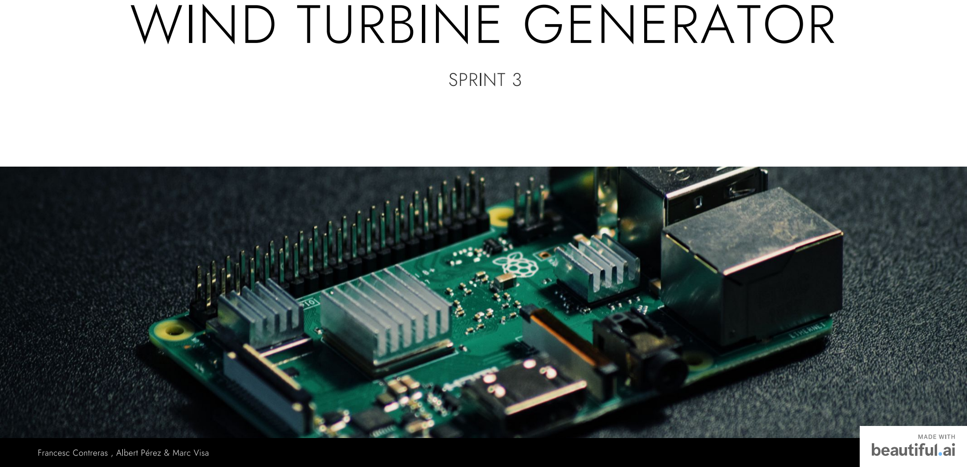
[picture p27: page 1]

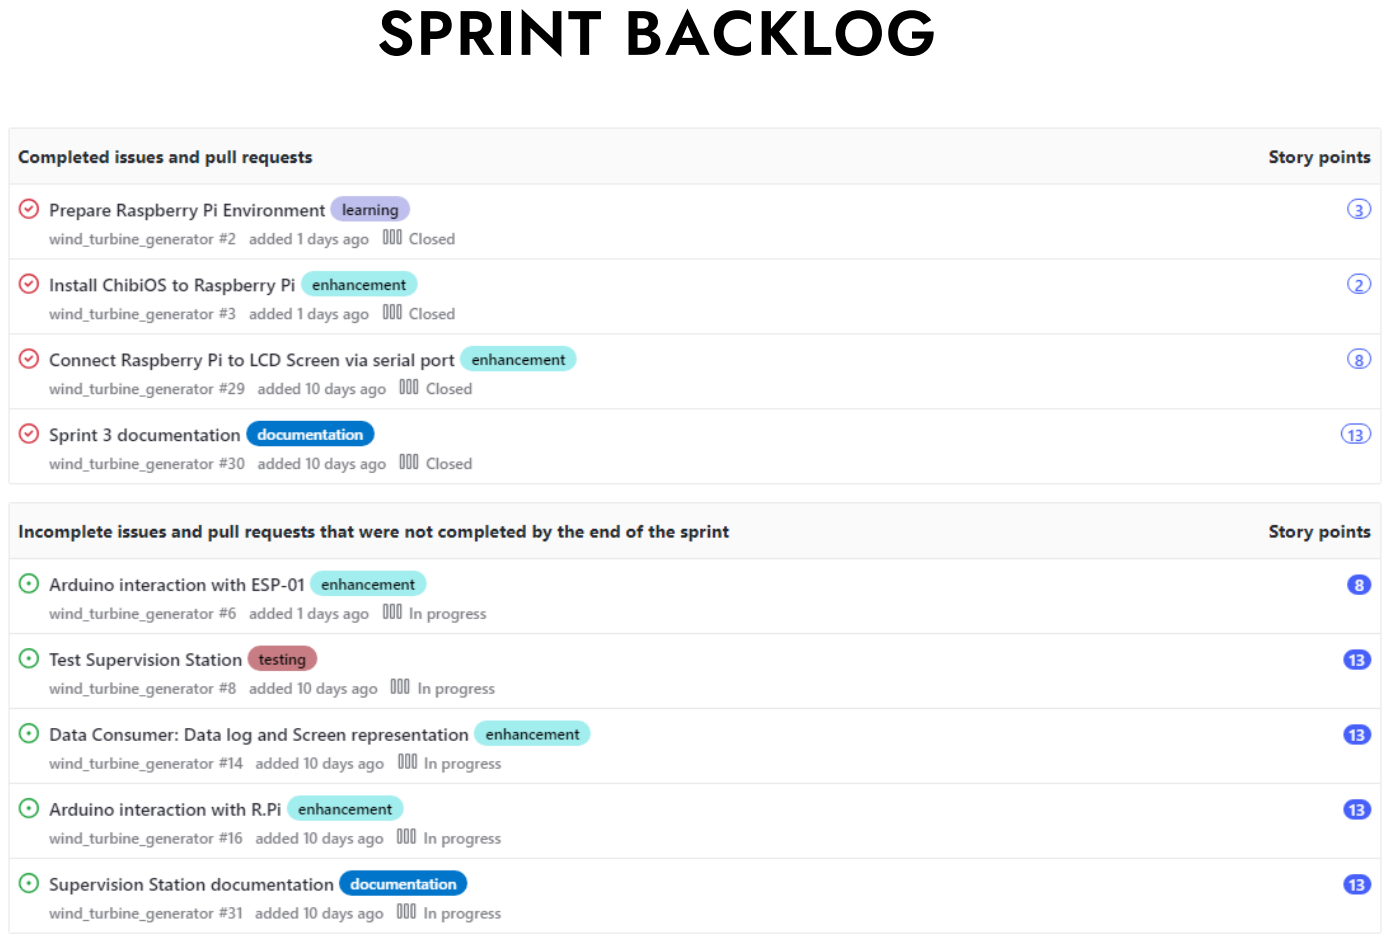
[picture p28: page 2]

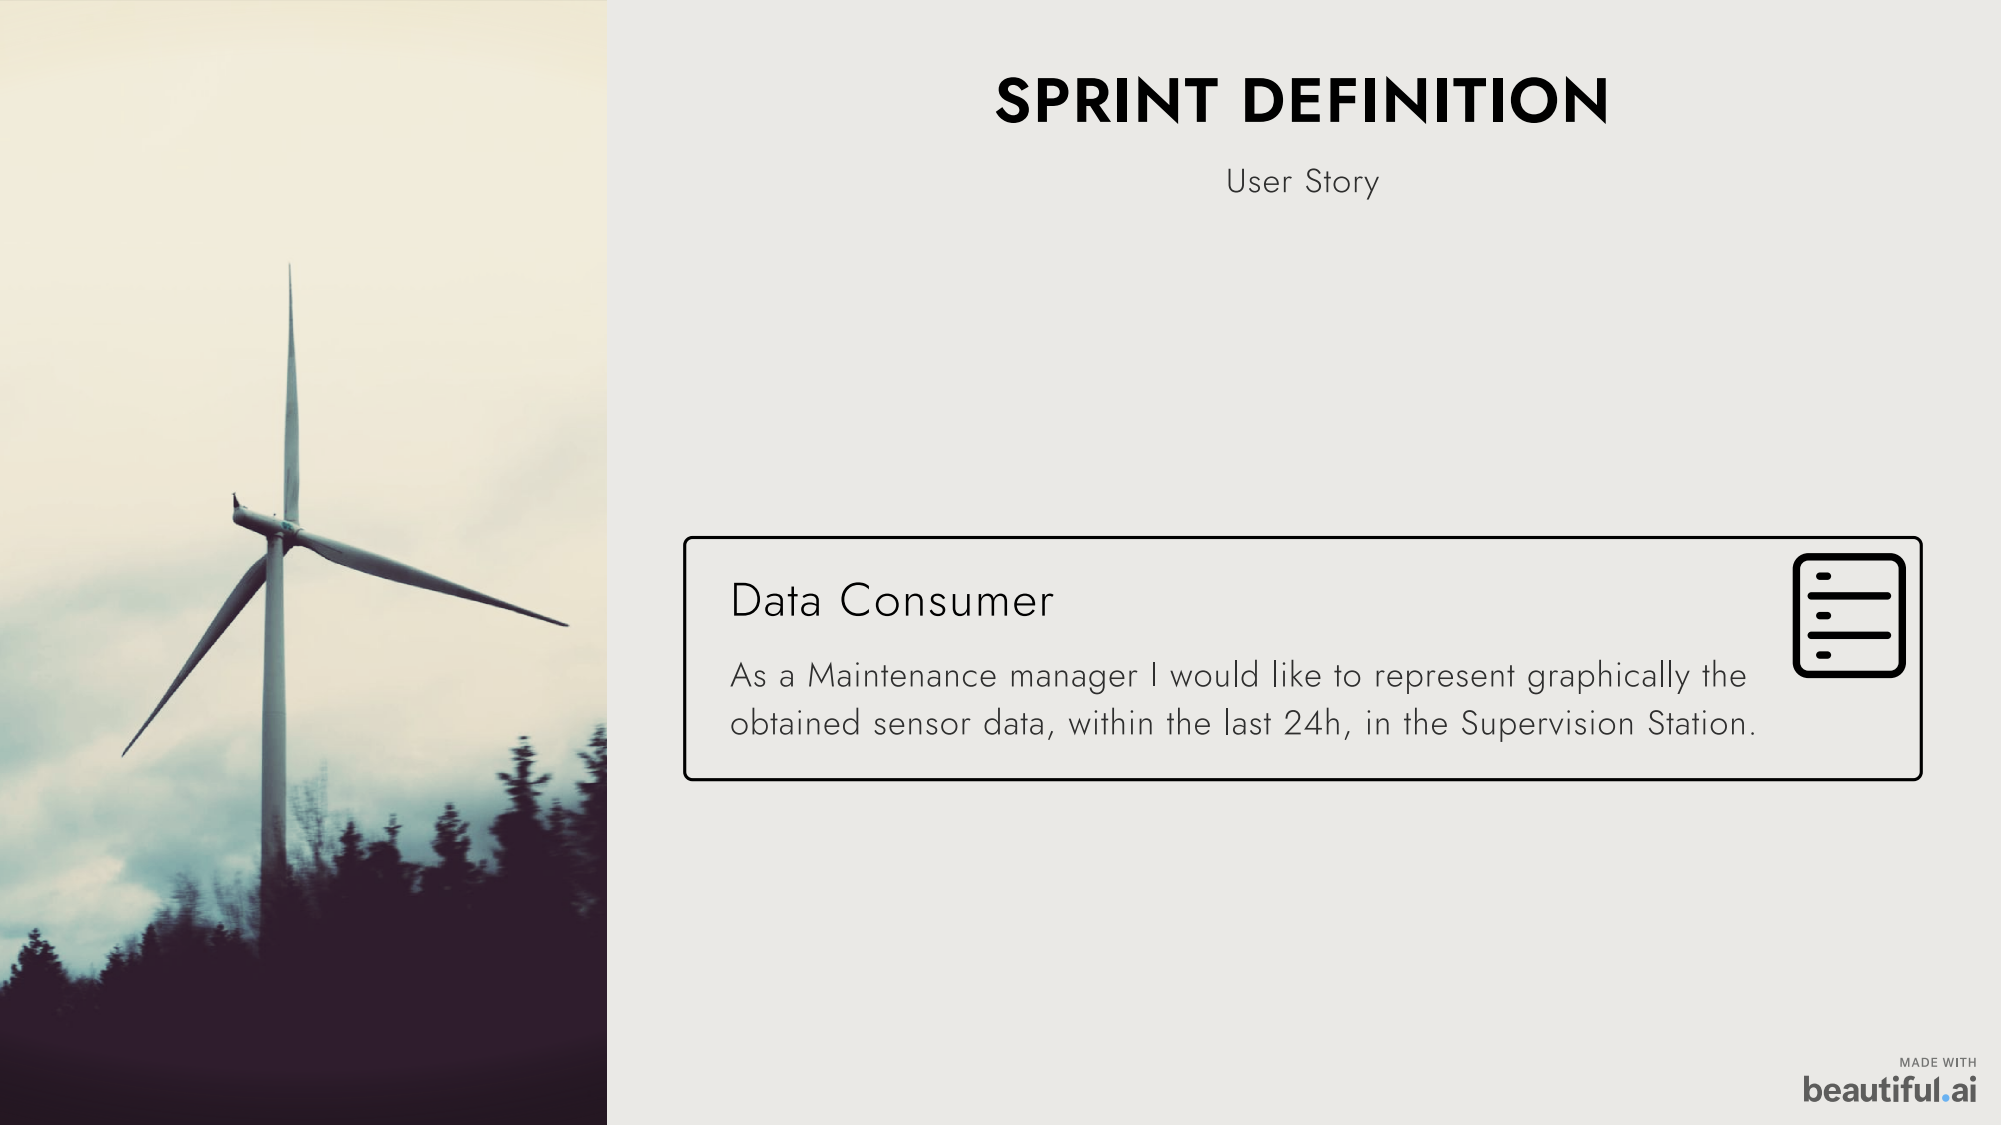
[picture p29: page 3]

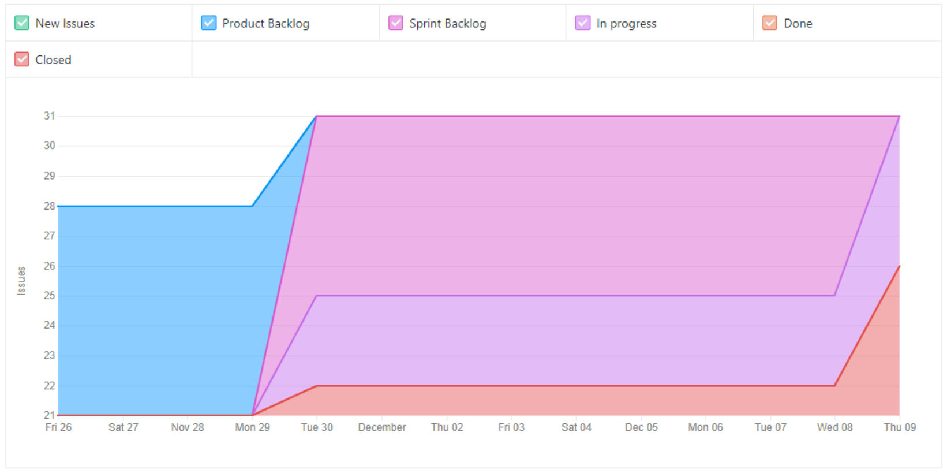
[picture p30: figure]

# 14 days

22h dedication time
52/86

story points completion

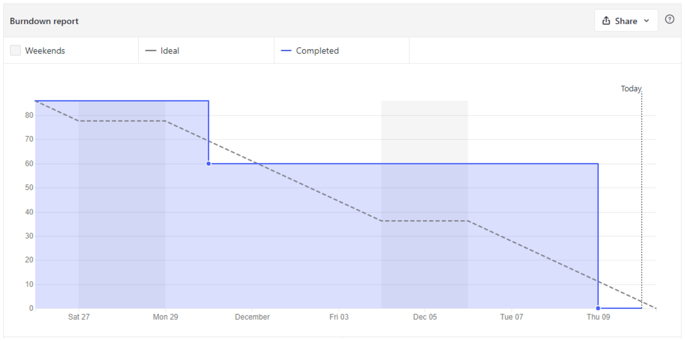
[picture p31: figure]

# 14 days

22h dedication time
52/86

story points completion

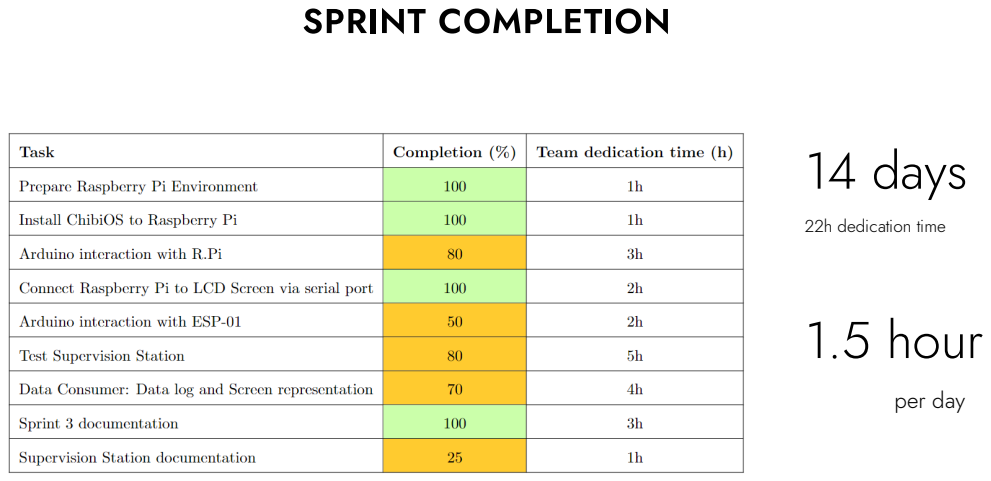
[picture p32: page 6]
14 days; 22h dedication time 1.5 hour; per day

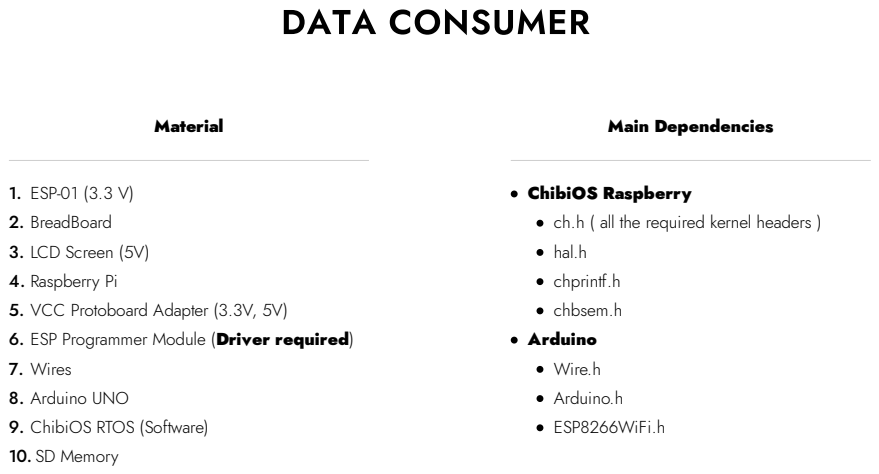
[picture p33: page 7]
Material; Main Dependencies

1. ESP-01 (3.3 V)
2. BreadBoard
3. LCD Screen (5V)
4. Raspberry Pi
5. VCC Protoboard Adapter (3.3V, 5V)
6. ESP Programmer Module (Driver required)
7. Wires
8. Arduino UNO
9. ChibiOS RTOS (Software)
10. SD Memory

ChibiOS Raspberry
ch.h ( all the required kernel headers )
hal.h
chprintf.h
chbsem.h
Arduino
Wire.h
Arduino.h
ESP8266WiFi.h

Master | Slave

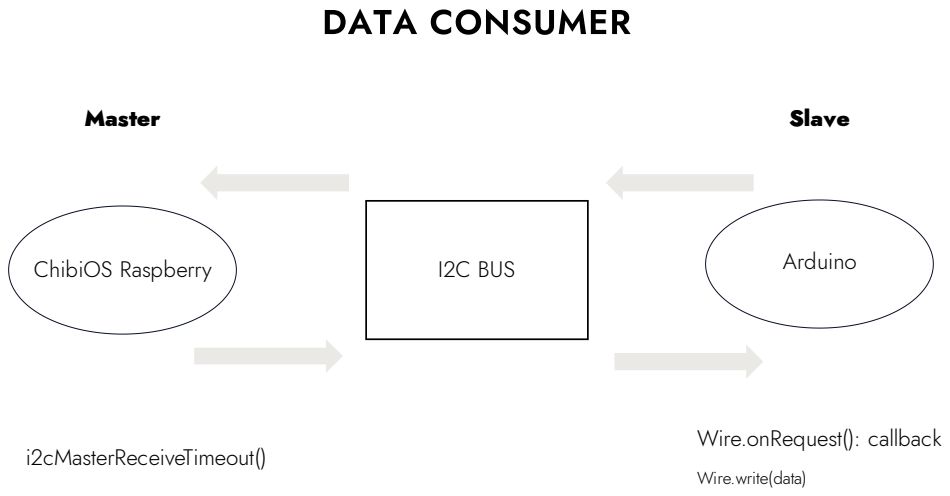
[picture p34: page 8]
ChibiOS Raspberry; Arduino; i2cMasterReceiveTimeout(); I2C BUS

Wire.onRequest(): callback
Wire.write(data)

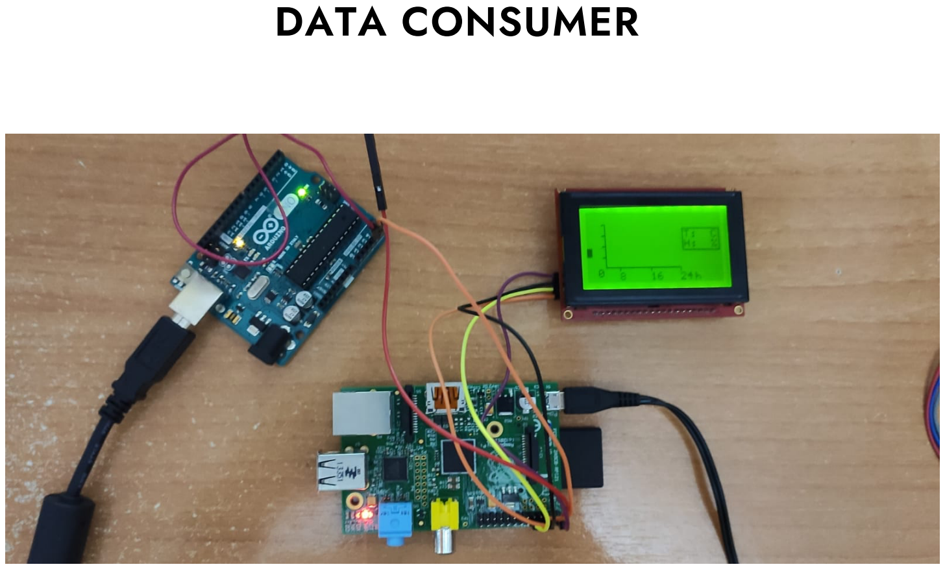
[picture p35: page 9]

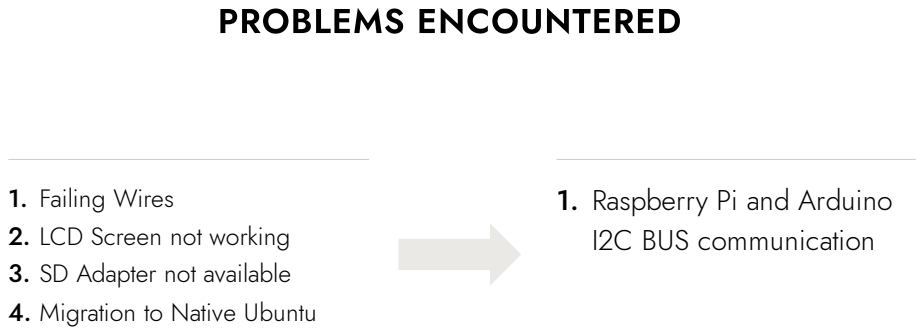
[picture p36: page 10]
ailin; Wir; kin; aila; ble; Mig; tio; tiv; uin; o I2C BUS communication

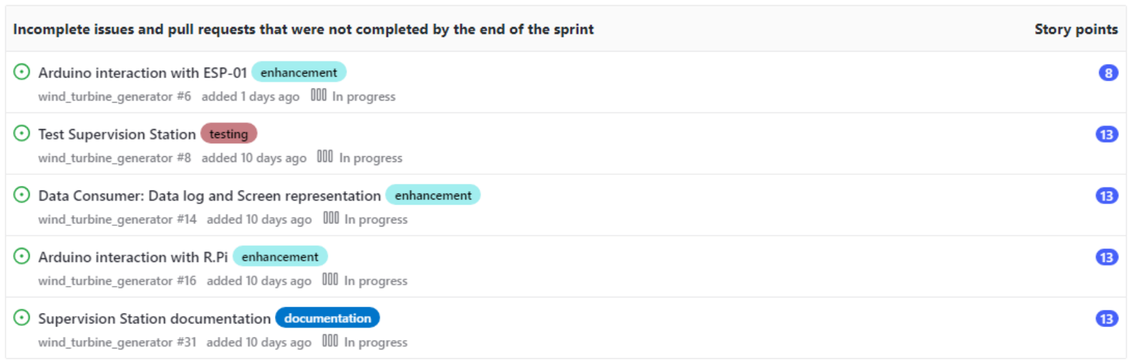
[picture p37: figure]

# Integration Test Whole project documentation

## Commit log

2021-11-06 Webserver with Temperature DHT11
2021-11-14 data producer 2 display and accelerometer
    [DataProducer2.fzz]
2021-11-17 update schema of dp2 and code of dp1
    [DataProducer2.fzz]
2021-11-20 Control LED broker
2021-11-20 mqtt_broker schema
    [NodeMCU+MCP23017.fzz]
2021-12-11 Arduino and ESP basic communication
2021-12-11 ESP-01 send data to Arduino
2021-12-12 Raspberry Pi
2021-12-12 Add schema SS
    [SupervisionStation.fzz]
2021-12-14 add i2c
2021-12-15 The End
    [SupervisionStation_v2.fzz]
2022-01-02 refactor skfolding
    [DataProducer2.fzz, NodeMCU+MCP23017.fzz, SupervisionStation.fzz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]
